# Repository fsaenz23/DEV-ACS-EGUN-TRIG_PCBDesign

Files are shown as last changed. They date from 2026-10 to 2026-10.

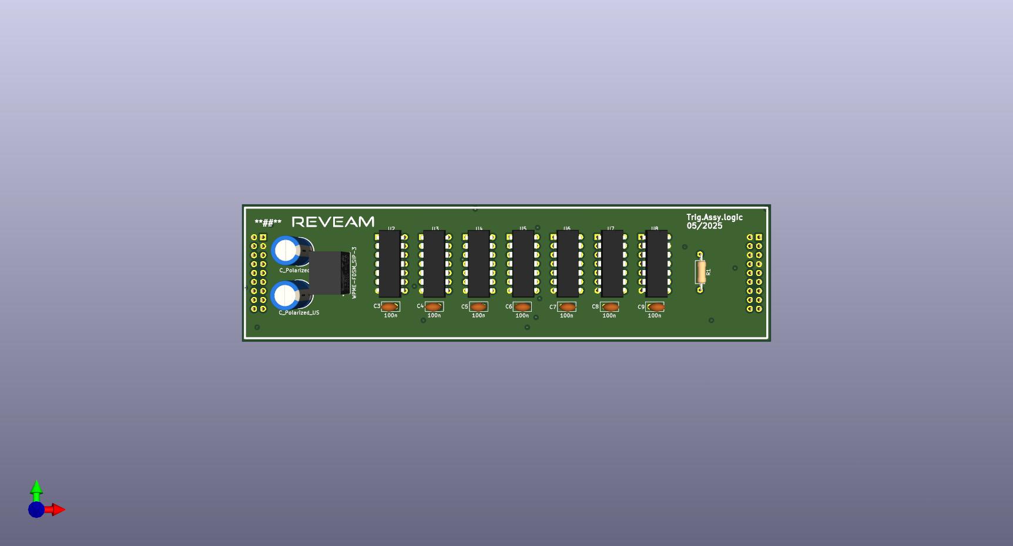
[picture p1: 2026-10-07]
Definition/Drawings/exports/Logic_Board/logicboard.jpg

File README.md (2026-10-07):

# DEV-ACS-EGUN-TRIG_PCBDesign

> The human/operator **front door** (fw-T4.C1.S1.SS4): it orients + routes, and links to deeper resources
> rather than restating them. Agents start at [`AGENTS.md`](AGENTS.md).

## What this is

This repository holds the **printed-circuit-board design of the Trigger Board Assembly** in the Reveam
Accelerator Control System (ACS): a 6-layer Base board and a 4-layer Logic board that plug together and
gate and drive a trigger pulse with isolated status feedback. It is for the engineers who maintain,
review, reorder, or later redesign the boards. It carries the KiCad sources, released Gerbers and reorder
kit, bills of materials, and system documentation, identified independently of any facility the assembly
is later instanced into.

Structural role: `asset-bearing Project`; `project_type`: `product`. asset_id / project_id:
`DEV-ACS-EGUN-TRIG_PCBDesign` (ACS -> EGUN -> TRIG, project-type token `PCBDesign`; cs-T5.C1.S3 /
cs-T5.C1.S17.SS1).

## Scope (fw-T11.C1.S1.SS1)

- **Subject:** the two-board Trigger Board Assembly PCB design (schematics, layouts, BOM, released
  fabrication outputs, system documentation).
- **Axis:** the asset itself -- the PCB design content.
- **Excludes:** firmware or control code (none exists; discrete logic); facility-side instancing
  (E-coded facility repos via `type_ref`); the governance bylaws (FW + CS, consumed as pinned
  submodules); the vendor fiber evaluation boards plugged into J7/J10; the planned all-SMD redesign
  (future, will branch from this baseline); and sibling ACS boards.

This human-prose Scope MUST agree with the machine-readable `scope:` block in
[`compatibility.yaml`](compatibility.yaml) (fw-T11.C1.S1.SS2).

## Status

- **Status:** Phase-2 bootstrap complete (pre-release, `v0.1.0`); the boards themselves are released and in production.
- **Owner:** Francisco Saenz (party `pty-francisco-saenz`; EntraID `fsaenz`). See [`Workflows/ownership/parties.yaml`](Workflows/ownership/parties.yaml).
- **Version:** see [`VERSION`](VERSION) (this repo's own rev). The full multi-module composition cover is the
  document meta-frontpage's job (fw-T8.C1.S11.SS8); this README states this repo's rev and links onward.

## Where things are (routing map)

- [`AGENTS.md`](AGENTS.md) -- **agents start here** (the operating contract + session-start reading order, fw-T7.C1.S1).
- [`BOOTSTRAP.md`](BOOTSTRAP.md) -- the Phase-2 setup steps this repo was scaffolded with.
- [`Definition/`](Definition/) -- the design content: `Drawings/` (KiCad sources + exports), `Fabrication/` (Gerbers, reorder kit), `Equipment/` (BOMs), `Architecture/`, `Calculations/`, `Narratives/`.
- [`Workflows/`](Workflows/) -- the canonical lifecycle scripts (`validate` / `push` / `pull` / `tag` / `deliver`); how to run them: fw-T3.C1.S3 / fw-T3.C1.S9.
- [`Project/STANDING-STATE.md`](Project/STANDING-STATE.md) -- standing state for resuming work (plus optional `Project/dev-tasks/`, fw-T7.C1.S18 / fw-T4.C1.S17).
- [`change-log.md`](change-log.md) + [`minutes/`](minutes/) -- the history of what shipped and why.
- [`docs/`](docs/) -- human documentation (README / FUNCTIONAL / INTERFACES / CHANGES).
- [`Governance/`](Governance/) -- how this repo is governed (the consumed governance submodules + any local governance).

## How to use it

- **Operators:** run the `Workflows/` scripts in order -- `validate.ps1` -> `push.ps1` -> `tag.ps1` (`pull.ps1` to sync, `deliver.ps1` to cut a delivery baseline). Details: fw-T3.C1.S3.
- **Agents:** read `AGENTS.md` first (it routes you to the bylaws + guides).
- **Reordering boards:** start at [`Definition/Fabrication/README.md`](Definition/Fabrication/README.md).

---

*Map, not manual (fw-T4.C1.S1.SS4): this README points to `AGENTS.md`, the bylaws, and the scripts -- it does not restate them (single-source, fw-T11.C1.S2). Keep it current at release (status + version); the routing map is mostly static. `README.md` (humans) and `AGENTS.md` (agents) are the two parallel front doors.*

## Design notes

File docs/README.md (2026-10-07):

# DEV-ACS-EGUN-TRIG_PCBDesign

## Overview

This module is the printed-circuit-board design of the **Trigger Board Assembly** in the Reveam
Accelerator Control System (ACS): two stacked 1.6 mm boards, a 6-layer Base board and a 4-layer
Logic board, that accept a trigger, gate it with inhibit and mode logic, and drive the output
pulse while reporting isolated status. It holds the KiCad schematic and layout sources, the
released fabrication outputs, the bill of materials, and the system documentation. It is a design
artifact (`project_type: product`), identified independently of any facility it is later instanced
into. The released boards are in production; this repo records them as the baseline.

## Owner

Accountable owner: **Francisco Saenz** (party `pty-francisco-saenz`; EntraID `fsaenz`; see
[`Workflows/ownership/parties.yaml`](../Workflows/ownership/parties.yaml) and the per-system
record in [`Workflows/ownership/stakeholders.yaml`](../Workflows/ownership/stakeholders.yaml)).
This project runs `workflow_mode: direct` (single-committer; commits land on the main branch).

## Scope

Scope is declared machine-readably in [`compatibility.yaml`](../compatibility.yaml) per
fw-T11.C1.S1.SS2 and in human prose in the repo-root [`README.md`](../README.md) per
fw-T11.C1.S1.SS1. In short: this repo governs the two-board trigger assembly design content only.
It excludes firmware or control code, facility-side instancing, the consumed governance bylaws,
the vendor fiber evaluation boards, the future all-SMD redesign, and sibling ACS boards.

## How to use

Operators run the `Workflows/*.ps1` lifecycle scripts (`validate` -> `push` -> `tag`; `pull` to
sync, `deliver` to cut a delivery baseline) rather than raw git (fw-T3.C1.S3). Design content
lives under `Definition/`: `Drawings/` (KiCad sources, `exports/` for PDFs and renders),
`Fabrication/` (Gerbers and the JLCPCB reorder kit), `Equipment/` (BOMs), `Architecture/` (block
diagram), `Calculations/` (Falstad simulation) and `Narratives/` (system documentation and design
notes). To reorder bare boards start at `Definition/Fabrication/README.md`. Agents read
[`AGENTS.md`](../AGENTS.md) first.

## Where to look next

See [`FUNCTIONAL.md`](FUNCTIONAL.md) for what the assembly does, [`INTERFACES.md`](INTERFACES.md)
for its provided / required interfaces (narrating [`interfaces.yaml`](../interfaces.yaml)), and
[`CHANGES.md`](CHANGES.md) for how the design has evolved. The append-only ledger is
[`change-log.md`](../change-log.md); resumable state is
[`Project/STANDING-STATE.md`](../Project/STANDING-STATE.md). The full pin-by-pin reference is
`Definition/Narratives/trigger-board-system-documentation.pdf`.

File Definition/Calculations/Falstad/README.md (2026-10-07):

# Falstad simulation
- Final_Circuit.txt: Falstad circuit export (File > Import From Text in Falstad's circuit simulator to open it). Whole-system simulation of the trigger board assembly, made by Alex; one file for the assembly, not one per board.

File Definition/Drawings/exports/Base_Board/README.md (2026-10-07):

Add 3D renders here (KiCad: View > 3D Viewer > File > Export Current View as PNG). Top, bottom and an angled view per board.

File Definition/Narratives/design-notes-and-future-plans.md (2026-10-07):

# Design notes and future plans

This released version is the baseline. The all-SMD version will branch from it.

Recorded 2026-10-07 from the designer (Francisco). The released boards are in production and stay as they are.

## As-built decisions
- The fiber link uses modified fiber evaluation boards, not on-board optics. They plug into the base board headers J7 (output) and J10 (input). They were chosen because they were what Mouser/DigiKey had in stock.
- The evaluation board is AFBR-0548Z (Mouser 630-AFBR-0548Z), one board listed for J7 and J10 in Final_Trigger_Board_BOM.xlsx. Modification: the bent (right-angle) interface pins were removed and replaced with straight pins pointing vertically down, with the longer part of each pin on the side opposite the fiber ports, so the board plugs into the base board headers J7 and J10. The replacement pins are generic 3-position, 2.54 mm pitch header (no part number), cut from a longer strip on hand.
- C12 (100 uF 25 V) is a regular electrolytic capacitor from an Amazon capacitor kit (no part number; D 5.18 mm, H 11.37 mm, lead pitch 1.77 mm as bent), with its leads bent so the top PCB does not hit it. The original Final BOM MPN did not match and was replaced with "kit part".
- Logic R1 (10 k, 1%) is a resistor from a resistor kit (bands brown-black-black-red-brown), no part number. The original Final BOM MPN did not match and was replaced with "kit part".
- Final testing (Final Testing sheet of the BOM): two assemblies passed all 22 tests, including BNC and fiber input/output.
- Surface finish was ordered differently per board (base: ENIG with resin-plugged vias; logic: leaded HASL with oil-plugged vias). Keep as ordered for now. This likely explains why the two boards look different (gold vs silver pads), but that has not been confirmed with the fab.
- Orders: base 9354260A_Y6, logic 9354260A_Y8 (JLCPCB). Ordered files match the files in Base_Board/Gerbers and Logic_Board/Gerbers.

## Future plans (not started)
1. Redesign with all-SMD parts so the boards can be assembled with parts placed by the fab (SMT assembly), replacing the through-hole ICs, networks and connectors where possible.
2. Remove the fiber evaluation boards and put the fiber transmitter/receiver on the board itself. The supporting passives for those parts are only needed at that point.
3. With SMD parts, consider merging the base and logic boards into one board sized to fit the Phoenix enclosure used for this assembly.

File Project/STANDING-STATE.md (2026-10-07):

---
current_version: dev-acs-egun-trig-pcbdesign-v0.1.0
---

# Standing State

> Per fw-T7.C1.S18.SS1 -- the MANDATORY agent-resume record (Session Continuity & Roadmap Maintenance).
> A new or replacement agent reads this FIRST to resume (SS1), and keeps it current as work proceeds and
> before handing off (SS2). Pairs with the OPTIONAL dev-tracking surface (Project/dev-tasks/, fw-T4.C1.S17,
> if enabled) and the latest change-log / minutes.

## Operator-engagement block (FW-canonical default; re-surfaced per fw-T7.C1.S18.SS3)

Per fw-T7.C1.S18.SS3, paste this block verbatim at the top of every resume / handoff / continuation
prompt so a fresh agent is reminded how the operator wants to be engaged. The block CONTENT is
single-sourced from FW's pinned operator-engagement-block.md (fw-T11.C1.S2) and inlined below at
scaffold time; this project MAY override or extend its own copy, but the re-surfacing obligation
itself is not overridable.

> FALLBACK POINTER (pinned FW operator-engagement-block.md absent at emit time -- NOT the canonical text).
> Read the canonical block from the pinned submodule at
> Governance/_GOV-DesignFramework/Definition/References/templates/operator-engagement-block.md and paste
> it here verbatim. Per fw-T7.C1.S18.SS3 this block is re-surfaced at every resume / handoff; per
> fw-T11.C1.S2 its content is single-sourced from the FW artifact, never hardcoded in a consumer.

## Current standing state
- Phase: Phase 2 content populated 2026-10-07 (uncommitted); name gate CANONICAL, validate.ps1 PASS
- Classification: DEV-ACS-EGUN-TRIG_PCBDesign (ACS -> EGUN -> TRIG; function TimingSignal; type-class PCB; discipline D040)
- Owner: pty-francisco-saenz (EntraID fsaenz)
- Layout: flat (no eigen-module; no composition.yaml); two boards under Definition/Drawings/{Base_Board,Logic_Board}
- Design content: released Base ("pin version") + Logic (rev 0.2) boards; source package C:\Repos\Trigger_Board_Package left untouched
- Pins: see compatibility.yaml (governance_pins)
- Last shipped: none yet

## Next steps
- [x] Name gate: CANONICAL (advisory only: PCBDesign not in catalogued project-type set).
- [x] Workflows/validate.ps1: PASS, 0 errors.
- [ ] Commit + push via Workflows/push.ps1 (choose remote); tag via Workflows/tag.ps1.

## Open decisions / parked
- Two ORDER_SPEC.md files fail Definition/Fabrication/CHECKSUMS.sha256 (edited after checksums); regenerate if wanted.
- Functional descriptions in the system documentation (section 1) still to be confirmed against design intent.
- Optional full Gerber check (silkscreen, paste, pad shapes) not done.

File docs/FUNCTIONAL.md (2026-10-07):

# DEV-ACS-EGUN-TRIG_PCBDesign -- Functional Description

## Purpose

The assembly receives an external trigger, decides whether it may pass, and drives the resulting
output pulse, while reporting its state through isolated status outputs. It supports normal
(continuous) and one-shot operation, local and remote mode selection, and three independent
external inhibit inputs. Functional behavior below is derived from the schematic netlist and
should be read against design intent (see the system documentation, section 1).

## Inputs

The assembly consumes a trigger on BNC J6 or fiber header J10 (selected by JP2, with an optional
50 ohm termination on JP3), 24 V DC power on terminal block J1, a separate external 24 V for the
isolated I/O, three opto-isolated inhibit inputs, external one-shot select and arm inputs, and
local operator controls (mode switches SW2/SW3 and the one-shot push button SW1). These
correspond to the `required` interfaces in [`interfaces.yaml`](../interfaces.yaml).

## Outputs

The assembly produces the gated trigger pulse, driven by IC1 (IXDN614PI) onto BNC J5 or fiber
header J7 (selected by JP1, with an optional 50 ohm load on JP4), and opto-isolated status
feedback on terminal block J3 (remote, local, armed, one-shot, normal, power, trigger and
inhibit-summary states). These correspond to the `provided` interfaces in
[`interfaces.yaml`](../interfaces.yaml).

## Operating modes

Local and remote selection (SW2) and normal versus one-shot operation (SW3, with the SW1 push
button or the external arm / one-shot inputs) set the mode; the Logic board state logic produces
the armed, one-shot, normal and local / remote status. In any mode, an asserted inhibit (inputs
1 to 3, summed in the Base board logic) stops output pulses. Timing is set by monostables U4
(74LS221) and U9 (74AHCT123) with the component values listed in the system documentation.
Final testing recorded 22 tests passed on two assemblies, covering BNC and fiber input and
output, inhibits 1 to 3, the one-shot button, mode switches and the termination jumpers.

## Dependencies

The assembly depends on a 24 V supply for the Base board (the Logic board is fed through board
connector J2) and on an external 24 V for the isolated status and input side. The fiber paths
depend on modified AFBR-0548Z evaluation boards plugged into J7 and J10, which are sourced
separately. Upstream and downstream consumers of the trigger, inhibit and status signals are
facility-side and are bound at instancing. It consumes the pinned FW + CS governance submodules
for structure and lifecycle tooling; it authors none of that governance itself.

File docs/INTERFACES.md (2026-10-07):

# DEV-ACS-EGUN-TRIG_PCBDesign -- Interfaces

This narrates [`interfaces.yaml`](../interfaces.yaml) (fw-T9.C1.S5) for human readers. Each
subsection is keyed by the interface `id`. All interfaces are `lifecycle: active`: the boards are
released and in production. The board-to-board connectors (Base J8 to Logic J1, Base J2 to Logic
J2) are internal to the assembly and are documented in the system documentation, section 2.

## Provided interfaces

- **`trigger-output-bnc`** (`electrical`) -- the gated trigger pulse on BNC J5, driven by IC1
  (IXDN614PI), with an optional 50 ohm load (JP4). Selected with JP1. Change-sensitive on the
  connector, drive level and pulse width.
- **`trigger-output-fiber`** (`optical`) -- the same pulse on 3-pin header J7 (signal, GND, 5 V),
  feeding a fiber transmitter evaluation board. Selected with JP1.
- **`status-outputs`** (`electrical`) -- opto-isolated feedback on terminal block J3: remote,
  local, armed, one-shot, normal, power, trigger and inhibit-summary states plus per-inhibit
  status, powered from the external 24 V.

## Required interfaces

- **`trigger-input-bnc`** (`electrical`) -- external trigger on BNC J6, with optional 50 ohm
  termination (JP3). Selected with JP2.
- **`trigger-input-fiber`** (`optical`) -- external trigger from a fiber receiver evaluation board
  on 3-pin header J10 (signal, GND, 5 V). Selected with JP2.
- **`dc-power-in`** (`electrical`) -- 24 V and ground on J1 pins 1-2; each board's WPME-FDSM
  converter derives 5 V.
- **`isolated-24v-in`** (`electrical`) -- separate external 24 V and return (EXT_24V / EXT_GND) on
  J1 for the isolated I/O side.
- **`inhibit-inputs`** (`electrical`) -- three opto-isolated inhibit inputs on J1; any asserted
  inhibit stops output pulses.
- **`remote-control-inputs`** (`electrical`) -- external one-shot select and arm inputs on J1.

## Bidirectional interfaces

- (none) -- the assembly has no peer-bidirectional interfaces.

## Change-sensitive surfaces

The union of change-sensitive fields: `connector_type`, `logic_level`, `termination`
(trigger-input-bnc); `header_pinout`, `fiber_receiver_module` (trigger-input-fiber);
`connector_type`, `drive_level`, `pulse_width` (trigger-output-bnc); `header_pinout`,
`fiber_transmitter_module` (trigger-output-fiber); `rail_voltage`, `current_budget`,
`terminal_pinout` (dc-power-in); `rail_voltage`, `terminal_pinout` (isolated-24v-in);
`input_polarity`, `isolation`, `terminal_pinout` (inhibit-inputs, remote-control-inputs);
`signal_set`, `isolation`, `terminal_pinout` (status-outputs). A change to any of these alters
what connected equipment must expect -- notify the owners of the connected trigger source,
interlock and monitoring equipment before revising them, and co-change this narrative in the same
commit (fw-T9.C1.S5.SS8).

## Superseded interfaces

- (none)

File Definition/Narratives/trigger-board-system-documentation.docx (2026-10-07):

# Trigger Board Assembly

System documentation: pin-by-pin reference, block diagram, board interconnect and bill of materials

Prepared 2026-10-06 from the released KiCad projects (Base_Board rev "pin version", Logic_Board rev 0.2). No design changes are implied by this document.

# 1. System overview

The Trigger Board Assembly is two stacked 1.6 mm boards: the Base board has 6 copper layers (F.Cu, In1-In4, B.Cu) and the Logic board has 4 (F.Cu, In1, In2, B.Cu). The Logic board (150 x 39 mm) plugs onto the Base board through two 2x9 connectors: Base J8 (socket) mates with Logic J1 (pin header), and Base J2 (socket) mates with Logic J2 (pin header). Each board has its own 24 V to 5 V DC-DC converter.

Functional summary, derived from the schematic netlist (verify against design intent):

- Trigger path: an external trigger enters on BNC J6 or fiber header J10 (JP2 selects), optionally terminated in 50 ohm (JP3), and goes to the Logic board as Trig_In on J8 pin 1. The output pulse is driven by IC1 (IXDN614PI) as Trig_Out onto BNC J5 or fiber header J7 (JP1 selects; JP4 adds a 50 ohm load).
- Gating: three opto-isolated external inhibit inputs (J1 pins 7, 9, 11) and the Logic board decision signal In_from_lgboard are ANDed in U6 to form the IC1 input. JP5 and JP6 can force two of the inhibit channels to 5 V.
- Timing: U4 (74LS221) generates Master_TO_Out and Slave_TO_Out. Unit 1 uses C12 100 uF with R14 22 k (about 1.5 s, estimated 0.7 x R x C); unit 2 uses C4 1 nF with R13 1.5 k (about 1 us). U9 (74AHCT123) stretches the output pulse into Trig_Sts using C13 10 uF and R31 100 k (about 0.45 s, estimated 0.45 x R x C).
- Status: Remote, Local, Armed, OneShot, Normal, Power, Trigger and inhibit-summary states are passed through quad optocouplers (U2, U7, U8) to the isolated terminal block J3, powered from the external 24 V (EXT_24V).
- Mode selection: base switches SW2 and SW3 and push button SW1 drive the switch1/switch2 lines, the Arm/one-shot timer input and the Remote status net toward the Logic board.
- Logic board: NAND/AND/OR logic (U2-U5 SN74ACT00, U6 74AHCT04, U7 74LS08, U8 4075) forms the armed / one-shot / normal / remote-local state logic and returns In_from_lgboard and OR_Out.

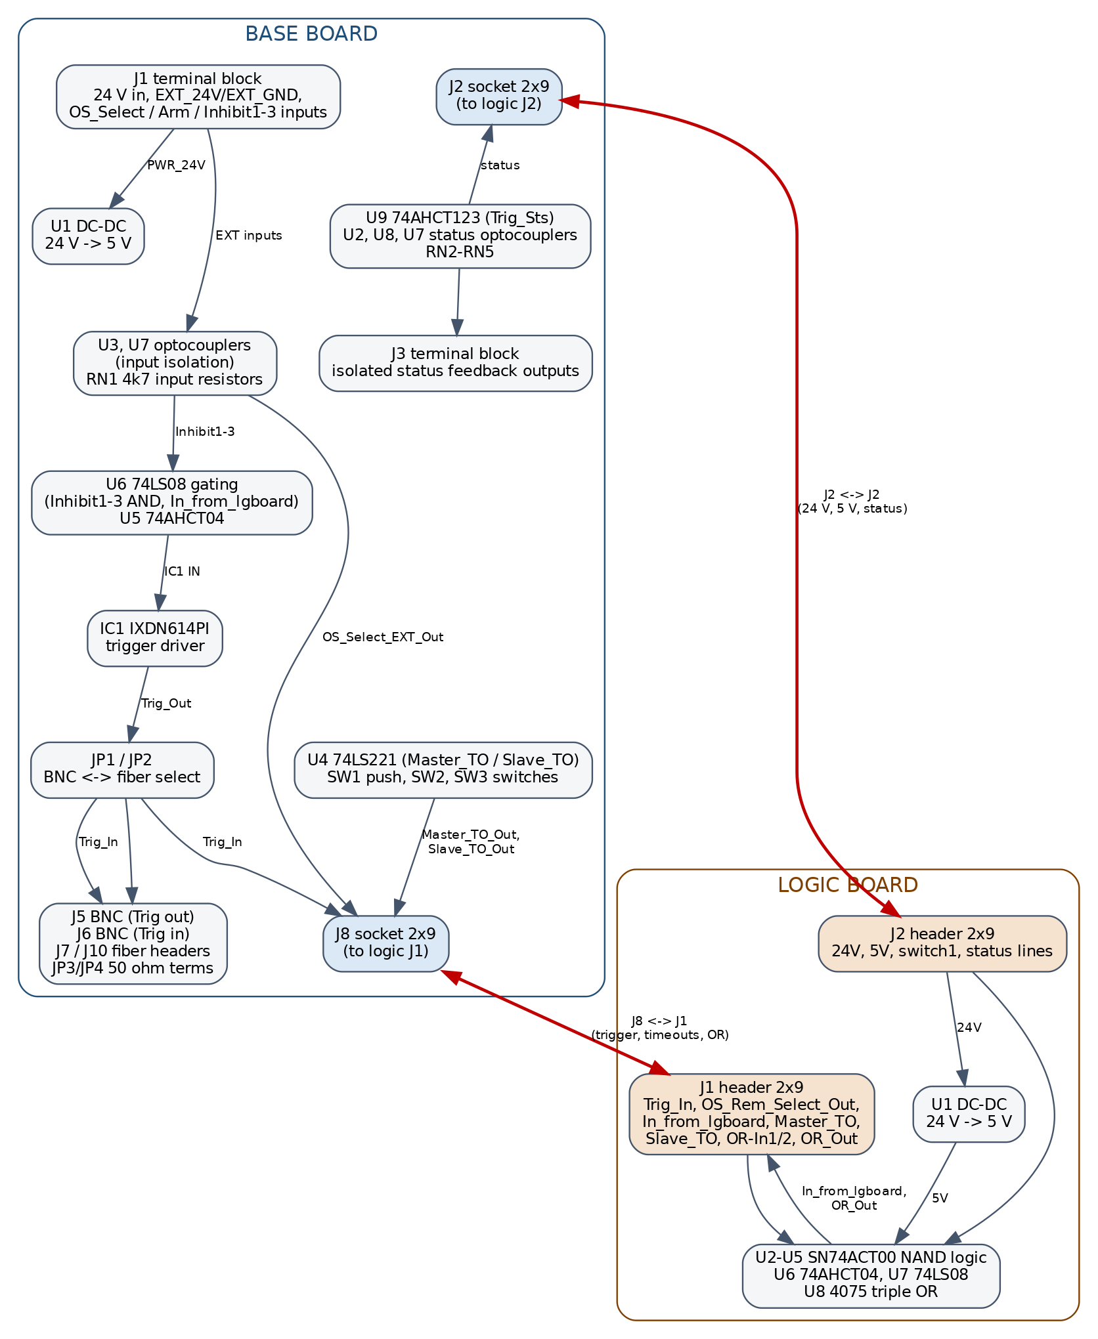
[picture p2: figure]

Figure 1. System block diagram (base + logic). Source: block_diagram.png in this folder.

# 2. Board-to-board interconnect

Base J8 plugs into Logic J1 and Base J2 plugs into Logic J2 (confirmed by the designer). Pins mate n to n; net names match on every populated pin of J8/J1, which supports this.

## 2.1 Base J8 to Logic J1

Pin | Base J8 net | Logic J1 net | Note
1 | Trig_In | Trig_In
2 | GND | GND
3 | OS_Select_EXT_Out | OS_Rem_Select_Out | name differs
4 | In_from_lgboard | In_from_lgboard
5 | Master_TO_Out | Master_TO
6 | GND | GND
7 | GND | GND
8 | Slave_TO_Out | Slave_TO
9 | NC | NC | spare
10 | NC | NC | spare
11 | NC | NC | spare
12 | NC | NC | spare
13 | NC | NC | spare
14 | NC | NC | spare
15 | NC | NC | spare
16 | OR-In1 | OR-In1
17 | OR-In2 | OR-In2
18 | OR_Out | OR_Out

## 2.2 Base J2 to Logic J2

Pin | Base J2 net | Logic J2 net | Note
1 | PWR_24V | 24V
2 | GND | GND
3 | GND | GND
4 | NC | NC | spare
5 | lg_5V_sts | 5V | name differs
6 | switch2pin | Remote Sts | name differs
7 | switch1pin | switch1pin
8 | switch1opt | switch1opt
9 | NC | NC | spare
10 | NC | NC | spare
11 | NC | NC | spare
12 | NC | NC | spare
13 | NC | NC | spare
14 | Normal_Sts | Normal_Sts
15 | OneShot_Sts | OneShot_Sts
16 | Armed_Sts | Armed_Sts
17 | Local_Sts | Local_Sts
18 | Remote Sts | Remote Sts

Notes on differing names (J2): pin 1 is the 24 V rail named PWR_24V on the base and 24V on the logic board. Pin 5 is the logic board 5 V rail, read on the base as lg_5V_sts (5 V present sense). Pin 6 is switch2pin on the base (SW2 output) and lands on the Logic Remote Sts net, which is also on pin 18; so SW2 on the base (the remote/local selector) drives the Logic board Remote Sts net, as intended (confirmed by the designer). Naming differences on J8 (Master_TO_Out vs Master_TO, Slave_TO_Out vs Slave_TO, OS_Select_EXT_Out vs OS_Rem_Select_Out, GND vs /GND) are the same signals.

# 3. Base board pinouts

## 3.1 J1: Field terminal block (Phoenix Contact 1700812, 18 positions): 24 V power, external isolated 24 V and inputs

Pin | Function / pad name | Net
1 | 1 | PWR_24V
2 | 2 | GND
3 | 3 | EXT_24V
4 | 4 | EXT_GND
5 | 5 | OS_Select_EXT
6 | 6 | Arm_OS_EXT
7 | 7 | Inhibit1_EXT
8 | 8 | NC
9 | 9 | Inhibit2_EXT
10 | 10 | Inhibit2_EXT_GND
11 | 11 | Inhibit3_EXT
12 | 12 | Inhibit3_EXT_GND
13 | 13 | NC
14 | 14 | NC
15 | 15 | NC
16 | 16 | NC
17 | 17 | NC
18 | 18 | NC

## 3.2 J3: Field terminal block (Phoenix Contact 1700812, 18 positions): isolated status outputs

Pin | Function / pad name | Net
1 | 1 | NC
2 | 2 | NC
3 | 3 | Rmt_Sts_FB
4 | 4 | Local_Sts_FB
5 | 5 | Inhib_Summ_FB
6 | 6 | Armed_Sts_FB
7 | 7 | Normal_Sts_FB
8 | 8 | OneShot_Sts_FB
9 | 9 | NC
10 | 10 | Pwr_Sts_FB
11 | 11 | NC
12 | 12 | Trg_Sts_FB
13 | 13 | NC
14 | 14 | Inhibit1_Sts_FB
15 | 15 | Inhibit2_Sts
16 | 16 | Inhibit2_Sts_FB
17 | 17 | Inhibit3_Sts
18 | 18 | Inhibit3_Sts_FB

## 3.3 J2: 2x9 socket to Logic J2

Pin | Function / pad name | Net
1 | Pin_1 | PWR_24V
2 | Pin_2 | GND
3 | Pin_3 | GND
4 | Pin_4 | NC
5 | Pin_5 | lg_5V_sts
6 | Pin_6 | switch2pin
7 | Pin_7 | switch1pin
8 | Pin_8 | switch1opt
9 | Pin_9 | NC
10 | Pin_10 | NC
11 | Pin_11 | NC
12 | Pin_12 | NC
13 | Pin_13 | NC
14 | Pin_14 | Normal_Sts
15 | Pin_15 | OneShot_Sts
16 | Pin_16 | Armed_Sts
17 | Pin_17 | Local_Sts
18 | Pin_18 | Remote Sts

## 3.4 J8: 2x9 socket to Logic J1

Pin | Function / pad name | Net
1 | Pin_1 | Trig_In
2 | Pin_2 | GND
3 | Pin_3 | OS_Select_EXT_Out
4 | Pin_4 | In_from_lgboard
5 | Pin_5 | Master_TO_Out
6 | Pin_6 | GND
7 | Pin_7 | GND
8 | Pin_8 | Slave_TO_Out
9 | Pin_9 | NC
10 | Pin_10 | NC
11 | Pin_11 | NC
12 | Pin_12 | NC
13 | Pin_13 | NC
14 | Pin_14 | NC
15 | Pin_15 | NC
16 | Pin_16 | OR-In1
17 | Pin_17 | OR-In2
18 | Pin_18 | OR_Out

## 3.5 J5: BNC, trigger output

Pin | Function / pad name | Net
1 | In | (J5-In)
2 | Ext | GND

## 3.6 J6: BNC, trigger input

Pin | Function / pad name | Net
1 | In | (J6-In)
2 | Ext | GND

## 3.7 J7: 3-pin header, fiber transmitter (output side) connection

Pin | Function / pad name | Net
1 | Pin_1 | (J7-Pin_1)
2 | Pin_2 | GND
3 | Pin_3 | 5V

## 3.8 J10: 3-pin header, fiber receiver (input side) connection

Pin | Function / pad name | Net
1 | Pin_1 | (J10-Pin_1)
2 | Pin_2 | GND
3 | Pin_3 | 5V

J7/J10 fiber header assignments are inferred from jumper wiring (JP1 B to J7 pin 1; JP2 B to J10 pin 1): J7 carries the output trigger, J10 the input trigger. Pin 1 = signal, pin 2 = GND, pin 3 = 5 V.

## 3.9 Jumpers and switches

Ref | Pins and nets
JP1 | 1(A)=(J5-In); 2(C)=Trig_Out; 3(B)=(J7-Pin_1)
JP2 | 1(A)=(J6-In); 2(C)=Trig_In; 3(B)=(J10-Pin_1)
JP3 | 1(A)=(J6-In); 2(B)=(JP3-B)
JP4 | 1(A)=(JP4-A); 2(B)=(J5-In)
JP5 | 1(A)=5V; 2(B)=(JP5-B)
JP6 | 1(A)=5V; 2(B)=(JP6-B)
SW1 | 1(1)=(RN5A-R1.1); 2(2)=(U7-CT1)
SW2 | 1(B)=switch2pin; 2(C)=GND; 3(A)=5V
SW3 | 1(B)=switch1pin; 2(C)=GND; 3(A)=switch1opt

# 4. Logic board pinouts

## 4.1 J1: 2x9 pin header to Base J8

Pin | Net
1 | Trig_In
2 | GND
3 | OS_Rem_Select_Out
4 | In_from_lgboard
5 | Master_TO
6 | GND
7 | GND
8 | Slave_TO
9 | NC
10 | NC
11 | NC
12 | NC
13 | NC
14 | NC
15 | NC
16 | OR-In1
17 | OR-In2
18 | OR_Out

## 4.2 J2: 2x9 pin header to Base J2

Pin | Net
1 | 24V
2 | GND
3 | GND
4 | NC
5 | 5V
6 | Remote Sts
7 | switch1pin
8 | switch1opt
9 | NC
10 | NC
11 | NC
12 | NC
13 | NC
14 | Normal_Sts
15 | OneShot_Sts
16 | Armed_Sts
17 | Local_Sts
18 | Remote Sts

# 5. Integrated circuits: pin-by-pin

Net names in parentheses are local nets named after a pin they connect to. NC = no connection.

### Base IC1: IXDN614PI trigger driver (OUT1/OUT2 paralleled)

Pin | Function | Net
1 | VCC_1 | 5V
2 | IN | (IC1-IN)
3 | NC | NC
4 | GND_1 | GND
5 | GND_2 | GND
6 | OUT_1 | Trig_Out
7 | OUT_2 | Trig_Out
8 | VCC_2 | 5V

### Base U1: WPME-FDSM DC-DC, 24 V to 5 V

Pin | Function | Net
1 | 1 | PWR_24V
2 | 2 | GND
3 | 3 | 5V

### Base U2: PS2501L-4 optocoupler: status outputs

Pin | Function | Net
1 | A1 | (RN3D-R4.1)
2 | C1 | GND
3 | A2 | (RN3E-R5.1)
4 | C2 | GND
5 | A3 | (RN4A-R1.1)
6 | C3 | GND
7 | A4 | (RN4B-R2.1)
8 | C4 | GND
9 | ET4 | OneShot_Sts_FB
10 | CT4 | (RN5B-R2.2)
11 | ET3 | Armed_Sts_FB
12 | CT3 | (RN2F-R6.2)
13 | ET2 | Local_Sts_FB
14 | CT2 | (RN2E-R5.2)
15 | ET1 | Rmt_Sts_FB
16 | CT1 | (RN2D-R4.2)

### Base U3: PS2501L-4 optocoupler: external inputs (OS select, inhibits)

Pin | Function | Net
1 | A1 | (RN1A-R1.2)
2 | C1 | EXT_GND
3 | A2 | (RN1B-R2.2)
4 | C2 | EXT_GND
5 | A3 | (RN1C-R3.2)
6 | C3 | Inhibit2_EXT_GND
7 | A4 | (RN1D-R4.2)
8 | C4 | Inhibit3_EXT_GND
9 | ET4 | (JP5-B)
10 | CT4 | 5V
11 | ET3 | (JP6-B)
12 | CT3 | 5V
13 | ET2 | (RN6D-R4.2)
14 | CT2 | 5V
15 | ET1 | GND
16 | CT1 | OS_Select_EXT_Out

### Base U4: 74LS221 dual monostable

Pin | Function | Net
1 | ~{A} | GND
2 | B | (RN5A-R1.1)
3 | ~{CLR} | 5V
4 | ~{Q} | NC
5 | Q | NC
6 | Cext | (U4B-Cext)
7 | RCext | (U4B-RCext)
8 | GND | GND
9 | ~{A} | GND
10 | B | Master_TO_Out
11 | ~{CLR} | 5V
12 | ~{Q} | Slave_TO_Out
13 | Q | Master_TO_Out
14 | Cext | (U4A-Cext)
15 | RCext | (U4A-RCext)
16 | VCC | 5V

### Base U5: 74AHCT04 hex inverter

Pin | Function | Net
1 | | (RN6D-R4.2)
2 | | (RN3A-R1.2)
3 | | (JP6-B)
4 | | (RN3B-R2.2)
5 | | (JP5-B)
6 | | (RN3C-R3.2)
7 | GND | GND
8 | | OR-In2
9 | | lg_5V_sts
10 | | OR-In1
11 | | 5V
12 | | Pwr_Sts
13 | | OR_Out
14 | VCC | 5V

### Base U6: 74LS08 quad AND

Pin | Function | Net
1 | | (RN6D-R4.2)
2 | | (JP6-B)
3 | | (RN8B-R2.2)
4 | | (RN8B-R2.2)
5 | | (JP5-B)
6 | | (RN8C-R3.2)
7 | GND | GND
8 | | Inhib_Sum
9 | | (RN8C-R3.2)
10 | | 5V
11 | | (IC1-IN)
12 | | In_from_lgboard
13 | | (RN8C-R3.2)
14 | VCC | 5V

### Base U7: PS2501L-4 optocoupler: Arm input and inhibit status

Pin | Function | Net
1 | A1 | (RN1E-R5.2)
2 | C1 | EXT_GND
3 | A2 | (RN3A-R1.1)
4 | C2 | GND
5 | A3 | (RN3B-R2.1)
6 | C3 | GND
7 | A4 | (RN3C-R3.1)
8 | C4 | GND
9 | ET4 | Inhibit3_Sts_FB
10 | CT4 | (RN2C-R3.2)
11 | ET3 | Inhibit2_Sts_FB
12 | CT3 | (RN2B-R2.2)
13 | ET2 | Inhibit1_Sts_FB
14 | CT2 | (RN2A-R1.2)
15 | ET1 | (RN5A-R1.1)
16 | CT1 | (U7-CT1)

### Base U8: PS2501L-4 optocoupler: status outputs

Pin | Function | Net
1 | A1 | (RN4C-R3.1)
2 | C1 | GND
3 | A2 | (RN4D-R4.1)
4 | C2 | GND
5 | A3 | (RN4E-R5.1)
6 | C3 | GND
7 | A4 | (RN4F-R6.1)
8 | C4 | GND
9 | ET4 | Inhib_Summ_FB
10 | CT4 | (RN5F-R6.2)
11 | ET3 | Trg_Sts_FB
12 | CT3 | (RN5E-R5.2)
13 | ET2 | Pwr_Sts_FB
14 | CT2 | (RN5D-R4.2)
15 | ET1 | Normal_Sts_FB
16 | CT1 | (RN5C-R3.2)

### Base U9: 74AHCT123 dual monostable

Pin | Function | Net
1 | A | GND
2 | B | Trig_Out
3 | Clr | 5V
4 | ~{Q} | NC
5 | Q | NC
6 | Cext | NC
7 | RCext | NC
8 | GND | GND
9 | A | NC
10 | B | NC
11 | Clr | NC
12 | ~{Q} | NC
13 | Q | Trig_Sts
14 | Cext | GND
15 | RCext | (U9A-RCext)
16 | VCC | 5V

### Logic U1: WPME-FDSM DC-DC, 24 V to 5 V

Pin | Function | Net
1 | 1 | 24V
2 | 2 | GND
3 | 3 | 5V

### Logic U2: SN74ACT00

Pin | Function | Net
1 | | (U2-Pad1)
2 | | Master_TO
3 | | (U2-Pad3)
4 | | (U2-Pad3)
5 | | 5V
6 | | (U2-Pad13)
7 | GND | GND
8 | | (U2-Pad12)
9 | | Slave_TO
10 | | (U2-Pad10)
11 | | (U2-Pad10)
12 | | (U2-Pad12)
13 | | (U2-Pad13)
14 | VCC | 5V

### Logic U3: SN74ACT00

Pin | Function | Net
1 | | (U2-Pad12)
2 | | Trig_In
3 | | (U3-Pad3)
4 | | (U3-Pad4)
5 | | Trig_In
6 | | (U3-Pad12)
7 | GND | GND
8 | | (U3-Pad4)
9 | | (U2-Pad12)
10 | | 5V
11 | | (U3-Pad11)
12 | | (U3-Pad12)
13 | | Master_TO
14 | VCC | 5V

### Logic U4: SN74ACT00

Pin | Function | Net
1 | | (U3-Pad3)
2 | | (U4-Pad2)
3 | | (U4-Pad3)
4 | | (U4-Pad3)
5 | | (U4-Pad5)
6 | | (U4-Pad2)
7 | GND | GND
8 | | (U4-Pad5)
9 | | (U3-Pad11)
10 | | 5V
11 | | (U4-Pad11)
12 | | Trig_In
13 | | 5V
14 | VCC | 5V

### Logic U5: SN74ACT00

Pin | Function | Net
1 | | (U4-Pad3)
2 | | (U4-Pad11)
3 | | (U5-Pad3)
4 | | (U4-Pad2)
5 | | (U4-Pad11)
6 | | (U5-Pad13)
7 | GND | GND
8 | | Armed_Sts
9 | | (U5-Pad3)
10 | | (U2-Pad1)
11 | | (U2-Pad1)
12 | | Armed_Sts
13 | | (U5-Pad13)
14 | VCC | 5V

### Logic U6: 74AHCT04

Pin | Function | Net
1 | | Remote Sts
2 | | Local_Sts
3 | | OneShot_Sts
4 | | Normal_Sts
5 | | OS_Rem_Select_Out
6 | | (U6-Pad6)
7 | GND | GND
8 | | (U6-Pad8)
9 | | switch1pin
10 | | (U6-Pad10)
11 | | Remote Sts
12 | | switch1opt
13 | | Remote Sts
14 | VCC | 5V

### Logic U7: 74LS08

Pin | Function | Net
1 | | Remote Sts
2 | | (U6-Pad6)
3 | | (U7-Pad3)
4 | | (U6-Pad6)
5 | | (U6-Pad8)
6 | | (U7-Pad6)
7 | GND | GND
8 | | (U7-Pad8)
9 | | (U6-Pad8)
10 | | (U6-Pad10)
11 | | In_from_lgboard
12 | | Trig_In
13 | | (U7-Pad13)
14 | VCC | 5V

### Logic U8: 4075 triple OR

Pin | Function | Net
1 | | (U7-Pad3)
2 | | (U7-Pad6)
3 | | switch1pin
4 | | Armed_Sts
5 | | OS_Rem_Select_Out
6 | | (U7-Pad13)
7 | VSS | GND
8 | | (U7-Pad8)
9 | | OneShot_Sts
10 | | OR_Out
11 | | OR-In1
12 | | OR-In2
13 | | GND
14 | VDD | 5V

For 74xx devices, the gate-level pin functions follow the standard pinouts; the table lists the nets as routed.

# 6. Passive networks

Board | Ref | Value | Pin nets
Base | C1 | C_Polarized_US | 1=PWR_24V; 2=GND
Base | C10 | 100n | 1=5V; 2=GND
Base | C11 | 100n | 1=GND; 2=5V
Base | C12 | 100u | 1=(U4A-Cext); 2=(U4A-RCext)
Base | C13 | 10u | 1=(U9A-RCext); 2=GND
Base | C2 | C_Polarized_US | 1=5V; 2=GND
Base | C3 | 100n | 1=GND; 2=5V
Base | C4 | 1n | 1=(U4B-Cext); 2=(U4B-RCext)
Base | C5 | 100n | 1=(RN5A-R1.1); 2=GND
Base | C6 | 100n | 1=GND; 2=5V
Base | C7 | 100n | 1=GND; 2=5V
Base | R13 | 1k5 | 1=(U4B-RCext); 2=5V
Base | R14 | 22k | 1=(U4A-RCext); 2=5V
Base | R16 | 100 | 1=(U7-CT1); 2=5V
Base | R30 | 50_1W | 1=(JP4-A); 2=GND
Base | R31 | 100k | 1=(U9A-RCext); 2=5V
Base | R32 | 50_1W | 1=(JP3-B); 2=GND
Base | RN1 | 4k7 | 1=OS_Select_EXT; 2=(RN1A-R1.2); 3=Inhibit1_EXT; 4=(RN1B-R2.2); 5=Inhibit2_EXT; 6=(RN1C-R3.2); 7=Inhibit3_EXT; 8=(RN1D-R4.2); 9=Arm_OS_EXT; 10=(RN1E-R5.2)
Base | RN2 | 1k | 1=EXT_24V; 2=(RN2A-R1.2); 3=Inhibit2_Sts; 4=(RN2B-R2.2); 5=Inhibit3_Sts; 6=(RN2C-R3.2); 7=EXT_24V; 8=(RN2D-R4.2); 9=EXT_24V; 10=(RN2E-R5.2); 11=EXT_24V; 12=(RN2F-R6.2)
Base | RN3 | 470 | 1=(RN3A-R1.1); 2=(RN3A-R1.2); 3=(RN3B-R2.1); 4=(RN3B-R2.2); 5=(RN3C-R3.1); 6=(RN3C-R3.2); 7=(RN3D-R4.1); 8=Remote Sts; 9=(RN3E-R5.1); 10=Local_Sts
Base | RN4 | 470 | 1=(RN4A-R1.1); 2=Armed_Sts; 3=(RN4B-R2.1); 4=OneShot_Sts; 5=(RN4C-R3.1); 6=Normal_Sts; 7=(RN4D-R4.1); 8=Pwr_Sts; 9=(RN4E-R5.1); 10=Trig_Sts; 11=(RN4F-R6.1); 12=Inhib_Sum
Base | RN5 | 1k | 1=(RN5A-R1.1); 2=GND; 3=EXT_24V; 4=(RN5B-R2.2); 5=EXT_24V; 6=(RN5C-R3.2); 7=EXT_24V; 8=(RN5D-R4.2); 9=EXT_24V; 10=(RN5E-R5.2); 11=EXT_24V; 12=(RN5F-R6.2)
Base | RN6 | 10k | 1=GND; 2=NC; 3=OR_Out; 4=(JP6-B); 5=(RN6D-R4.2)
Base | RN7 | 10k | 1=GND; 2=(RN6D-R4.2); 3=(JP6-B); 4=(JP5-B); 5=lg_5V_sts
Base | RN8 | 10k | 1=GND; 2=(JP5-B); 3=(RN8B-R2.2); 4=(RN8C-R3.2); 5=In_from_lgboard
Logic | C1 | C_Polarized_US | 1=5V; 2=GND
Logic | C2 | C_Polarized_US | 1=24V; 2=GND
Logic | C3 | 100n | 1=GND; 2=5V
Logic | C4 | 100n | 1=GND; 2=5V
Logic | C5 | 100n | 1=GND; 2=5V
Logic | C6 | 100n | 1=GND; 2=5V
Logic | C7 | 100n | 1=GND; 2=5V
Logic | C8 | 100n | 1=GND; 2=5V
Logic | C9 | 100n | 1=GND; 2=5V
Logic | R1 | 10k | 1=Remote Sts; 2=OS_Rem_Select_Out

# 7. Bill of materials

Full BOM, with base and logic breakouts, is in Trigger_Board_System_BOM.xlsx. System totals below (R: ref prefix B = Base, L = Logic).

Qty | Ref(s) | Schematic value | Description | MFR part # | Mouser #
2 | B:C1, B:C2 | C_Polarized_US | 100uF 50V Electrolythic Capacitor | ESL107M050AGMAA | 80-ESL107M050AGMAA
6 | B:C3, B:C5, B:C6, B:C7, B:C10, B:C11 | 100n | 100nF Ceramic disk capacitor | S104Z93Z5VL83L0R | 594-S104Z93Z5VL83L0R
1 | B:C4 | 1n | 1nF Ceramic Disk Capacitor | FA28C0G1H102JNU00 | 810-FA28C0G1H10200
1 | B:C12 | 100u | 100uF 25V Electrolythic Capacitor | Kit part (no part number) | NA
1 | B:C13 | 10u | 10uF Ceramic Disk Capacitor | FG11X7R1H106KRT00 | 810-FG11X7R1H106KRT0
1 | B:IC1 | IXDN614PI | IXYS MOSFET Gate Driver | IXDN614PI | 849-IXDN614PI
1 | B:J1 | J6 | Screw Terminal Blocks | 1725041 | 651-1725041
2 | B:J2, B:J8 | Conn_02x09_Counter_Clockwise | 02x09 Pin Socket | 215307-9 | 571-215307-9
1 | B:J3 | 1700812 | Screw Terminal Blocks | 1725041 | 651-1725041
2 | B:J5, B:J6 | Conn_Coaxial | BNC female PCB mounted Connector | 1-1478204-0 | 571-1-1478204-0
2 | B:J7, B:J10 | Conn_01x03_Pin | Fiber RX/TX Eval boards. | AFBR-0548Z | 630-AFBR-0548Z
2 | B:JP1, B:JP2 | Jumper_3_Open | Jumper Pins (2 pin ones must be modded) - 6 used + 1 spare | 90120-0763 | 538-90120-0763
4 | B:JP3, B:JP4, B:JP5, B:JP6 | Jumper_2_Small_Open | Jumper Pins (2 pin ones must be modded) - 6 used + 1 spare | 90120-0763 | 538-90120-0763
1 | B:R13 | 1k5 | 1K5 ohm 1/4W | MFR-25FBF52-1K5 | 603-MFR-25FBF52-1K5
1 | B:R14 | 22k | 22Kohm 1/4W | MFR-25FTF52-22K | 603-MFR-25FTF52-22K
1 | B:R16 | 100 | 100 ohm 1/4W | MFR-25FBF52-100R | 603-MFR-25FBF52-100R
2 | B:R30, B:R32 | 50_1W | 50-Ohm 1W Resistor | PAC100005009FA1000 | 71-PAC100005009FA100
1 | B:R31 | 100k | 100K ohm 1/4W | MFR-25FTE52-100K | 603-MFR-25FTE52-100K
1 | B:RN1 | 4k7 | Resistor Network Isolated(4k7x05) | 770103472P | 774-770103472P
2 | B:RN2, B:RN5 | 1k | Resistor Network Isolated(1k06) | 4612X-102-102LF | 652-4612X-2LF-1K
1 | B:RN3 | 470 | Resistor Network Isolated (470x05) | 4610X-102-471LF | 652-4610X-2LF-470
1 | B:RN4 | 470 | Resistor Network Isolated (470x06) | 4612X-102-471LF | 652-4612X-2LF-470
3 | B:RN6, B:RN7, B:RN8 | 10k | Resistor Network Bussed(10Kx04) | 4605X-101-103FLF | 652-4605X-101-103FLF
1 | B:SW1 | SW_Push | Tactile switch | TS02-66-60-BK-260-LCR-D | 179-TS026660BK260LCR
2 | B:SW2, B:SW3 | SW_Wuerth_450301014042 | Wuerth Switch | 450301014042 | 710-450301014042
2 | B:U1, L:U1 | WPME-FDSM_SIP-3 | Wuerth Electronik Voltage Regulator | 173010578 | 710-173010578
4 | B:U2, B:U3, B:U7, B:U8 | PS2501L-4-A | 4-Channel OptoCoupler | PS2501-4-A | 551-PS2501-4-A
1 | B:U4 | 74LS221 | Texas Instruments Monostable Multivibrator | SN74LS221NE4 | 595-SN74LS221NE4
2 | B:U5, L:U6 | 74AHCT04 | Texas Instruments Hex Inverter | SN74AHCT04N | 595-SN74AHCT04N
1 | B:U6 | 74LS08 | Texas Instruments 4-Gate AND | SN74LS08N | 595-SN74LS08N
1 | B:U9 | 74AHCT123 | Texas Instruments Monostable Multivibrator | SN74AHCT123AN | 595-SN74AHCT123AN
2 | L:C1, L:C2 | C_Polarized_US | 100uF 50V Electrolythic Capacitor | ESL107M050AGMAA | 80-ESL107M050AGMAA
7 | L:C3, L:C4, L:C5, L:C6, L:C7, L:C8, L:C9 | 100n | 100 nF Ceramic disk capacitor | S104Z93Z5VL83L0R | 594-S104Z93Z5VL83L0R
2 | L:J1, L:J2 | Conn_02x09_Counter_Clockwise | 02x09 Pin Header | 826925-9 | 571-826925-9
1 | L:R1 | 10k | 10K 1% 1/4W Resistor | Kit part (no part number) | NA
4 | L:U2, L:U3, L:U4, L:U5 | SN74ACT00 | Texas Instruments Quad 2-Input NAND | SN74ACT00N | 595-SN74ACT00N
1 | L:U7 | 74LS08 | Texas Instruments 4-Gate AND | SN74LS08N | 595-SN74LS08N
1 | L:U8 | 4075 | Texas Instruments Triple 3-input OR Gate | CD4075BE | 595-CD4075BE

Not on the PCBs (see the Off-Board Items sheet of the BOM spreadsheet): the AFBR-0548Z fiber RX/TX evaluation board (qty 1, plugs into J7 and J10, modified), Phoenix Contact housing parts (2278500, 2278526, 2278542, 2 x 2896238), 6 jumper shunts (JM-2BK-61) and the bare PCBs. The source of part numbers is Final_Trigger_Board_BOM.xlsx.

Total: 72 parts (52 base, 20 logic), excluding bare PCBs, shunts, sockets and hardware.

# 8. BOM reconciliation and open items

Part numbers above come from Final_Trigger_Board_BOM.xlsx matched by reference designator. Every schematic reference appears in that BOM. Differences found:

- C4 and C13: the original Final BOM had the designators swapped. The board is correct (C4 marked 102 = 1 nF, C13 marked 106 = 10 uF, as in the schematic) and Final_Trigger_Board_BOM.xlsx is now corrected.
- C12: the fitted part is a regular 100 uF 25 V electrolytic from a capacitor kit (no part number), measured D 5.18 mm, H 11.37 mm, lead pitch 1.77 mm as bent, with its leads bent so the top PCB does not hit it. This matches the schematic. The original Final BOM MPN reads as 2.2 uF / 100 V and was replaced with kit part.
- Logic R1: the fitted resistor is 10 k, 1% (bands brown-black-black-red-brown), from a resistor kit with no part number. This matches the schematic. The original Final BOM MPN reads as 6.8 k and was replaced with kit part.
- The original Final BOM listed JP7 and JP10. These are the 3-pin 2.54 mm positions where the eval board pins are soldered, i.e. J7 and J10 in the schematic, not extra jumpers; they are not jumpers. There are 6 jumpers (JP1-JP6); the Final BOM quantity of 7 is 6 used plus 1 spare, so item 10 reads JP1-JP6, quantity 7 (6 + 1 spare).
- Logic U1 Mouser number was corrected to 710-173010578 to match base U1, and base U5 to 595-SN74AHCT04N (missing prefix).
- One AFBR-0548Z evaluation board (qty 1) is listed for both J7 and J10. The bent interface pins were removed and replaced with straight pins facing vertically down (longer part of the pins on the side opposite the fiber ports); the replacement pins are generic 3-position, 2.54 mm pitch header (no part number) cut from a longer strip on hand.
- Terminal blocks J1 and J3: the BOM lists 6 blocks of MPN 1725041 for 18 positions each, which resolves the earlier library-text/footprint question if that part is 3-position (not verified).
- Schematic symbol U2/U3/U7/U8 is PS2501L-4-A; the ordered part is PS2501-4-A in a DIP-16 footprint.
- Mating of J8/J1 and J2/J2 is confirmed by the designer (section 2). Functional descriptions in section 1 are derived from the netlist, not from design intent.

# 8.1 Assembly notes

- Fiber evaluation board (AFBR-0548Z): the bent interface pins were removed and replaced with straight pins facing vertically down, the longer part of the pins on the side opposite the fiber ports.
- Logic R1 (10 k, 1%): a resistor from a resistor kit (bands brown-black-black-red-brown), no part number.
- C12 (100 uF, 25 V): a regular electrolytic capacitor from an Amazon capacitor kit (no part number; D 5.18 mm, H 11.37 mm, lead pitch 1.77 mm as bent), with its leads bent so the top (logic) board does not hit it.

# 8.2 Final testing (from the Final Testing sheet)

Two assemblies were tested against 22 items. All items passed on both assemblies, including BNC and fiber input/output, inhibit 1-3, the one-shot button, local/remote and normal/one-shot switches, and the 50-ohm termination jumpers.

Test | Description | Assy 1 | Assy 2
50-ohm termination jumpers | 50 ohms across BNC connectors when jumper present. BNC open if jumper removed. | Pass | Pass
Local-Remote switch | Local and Remote status outputs toggle properly with switch input. | Pass | Pass
Normal-OS switch | Normal and OS feedbacks are triggered appropiately. | Pass | Pass
Power status feedback | HIGH(24V) when PWR and EXT PWR are present | Pass | Pass
Inhibbit Summation Status (inh2 jumper) | Triggered on inh2 jumper | Pass | Pass
Inhibbit Summation Status (inh3 jumper) | Triggered on inh3 jumper | Pass | Pass
Inhibit 1 feedback | triggers HIGH if inhibit 1 input LO and viceversa | Pass | Pass
input selection jumper | Propely labeled and selects the appropiate input | Pass | Pass
output selection jumper | Propely labeled and selects the appropiate output | Pass | Pass
Inhibit 2 jumper | Stops Pulses and relfects properly on INH summation | Pass | Pass
Inhibit 3 jumper | Stops Pulses and relfects properly on INH summation | Pass | Pass
Trigger_sts_fb | tested on BNC triggering | Pass | Pass
OS button | allows one pulse when proper switch setup and button pressede | Pass | Pass
inhibit 2 in/out | inhibit 2 input signal propelry closes the selected voltage on INH2 feedback. | Pass | Pass
inhibit 3 in/out | inhibit 3 input signal propelry closes the selected voltage on INH3 feedback. | Pass | Pass
Remote OS signal input | When swtiches are appropiate, remote OS is selected and Remote OS Signal is received a single pulse is observed at the output | Pass | Pass
BNC input | Input works properly | Pass | Pass
BNC output | Output works properly | Pass | Pass
Fiber input | Input works properly | Pass | Pass
fiber output | Output works properly | Pass | Pass
INH1 stops pulses | When pulsing, INH1 LOW stops the pulses. | Pass | Pass
INH2 stops pulses | When Pulsing INH2 LOW stops the pulses. | Pass | Pass
INH3 stops pulses | When Pulsing INH3 LOW stops the pulses. | Pass | Pass

# 9. Gerber verification (released Gerbers vs KiCad project files)

Checked 2026-10-06 by parsing the released Gerber/drill zips (generated 2025-05-30 by KiCad 8.0.8) and comparing them with Base_Board/KiCad/baseboard.kicad_pcb and Logic_Board/KiCad/logicboard.kicad_pcb. KiCad itself was not available, so the check compares geometry; it is not a byte-for-byte regeneration.

Item | Base board | Logic board
Copper tracks, every layer | all 966 match exactly (position, width) | all 369 match exactly
Zone fills | 22 of 22 identical | 3 of 3 present (count match)
Drill holes (PTH) | 389 of 389 within 1 um; no NPTH holes in either file | 173 of 173 exact
Board outline | 148 lines + 48 arcs, count match | 4 lines, count match
Solder-mask openings | 352 flashes, all at pad positions | 157 flashes, all at pad positions
Not verified | silkscreen, paste, pad/aperture sizes and shapes | same

Result: copper, drills, outline and mask openings in the released Gerbers match the current project files. The base PCB file was last saved 2025-06-17, after the 2025-05-30 Gerbers, but no geometry difference was found, so those later saves did not change the checked items.

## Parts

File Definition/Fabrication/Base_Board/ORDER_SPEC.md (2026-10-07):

# Base board - fabrication order specification

Reorder with: Gerbers_Baseboard-PinVersion.zip (this folder). Same files as Base_Board/Gerbers in the package.

| Item | Value |
| --- | --- |
| Board | Base board, "pin version" (KiCad project: Base_Board/KiCad/baseboard.kicad_pcb) |
| Last order | JLCPCB, order 9354260A_Y6, accounted 2025-05-30 (package: JLCPCB_Order_9354260A_Y6.zip) |
| Layers | 6 (F.Cu, In1-In4, B.Cu) |
| Size | 157.7 x 86.4 mm (from Edge_Cuts; matches the fab job file) |
| Thickness | 1.6 mm, FR-4 |
| Copper | 1 oz outer, 0.5 oz inner |
| Solder mask | Green |
| Silkscreen | White |
| Surface finish | ENIG (immersion gold) |
| Vias | Plugged with resin |
| Min drill | 0.30 mm (37 vias); through-hole sizes 0.6 to 1.524 mm |
| Narrowest track | 0.45 mm |
| Design software | KiCad 8.0.8 |
| Gerber set | 17 files: 6 copper, mask/paste/silk top and bottom, edge cuts, PTH and NPTH drill + drill maps |

Notes: finish differs from the logic board (see its spec); this is intentional: keep ENIG on the base board and reorder with the same finish. The board carries two fiber headers (J7, J10) for modified fiber evaluation boards that are NOT part of this order.
Source: fab job file 4te.json inside the JLCPCB package (Chinese-encoded; translated here).

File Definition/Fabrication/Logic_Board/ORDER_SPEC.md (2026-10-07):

# Logic board - fabrication order specification

Reorder with: Gerbers_Logicboard.zip (this folder). Same files as Logic_Board/Gerbers in the package.

| Item | Value |
| --- | --- |
| Board | Logic board rev 0.2 (KiCad project: Logic_Board/KiCad/logicboard.kicad_pcb) |
| Last order | JLCPCB, order 9354260A_Y8, accounted 2025-06-05. A replacement-file order for an earlier order (Y7) that was missing the drill layer. Package: JLCPCB_Order_9354260A_Y8.zip |
| Layers | 4 (F.Cu, In1, In2, B.Cu) |
| Size | 150.0 x 39.0 mm (from Edge_Cuts; matches the fab job file) |
| Thickness | 1.6 mm, FR-4 |
| Copper | 1 oz outer, 0.5 oz inner |
| Solder mask | Green |
| Silkscreen | White |
| Surface finish | HASL with lead (leaded) |
| Vias | Plugged with soldermask ("oil") |
| Min drill | 0.30 mm (16 vias); other holes 0.8 and 1.0 mm |
| Narrowest track | 0.50 mm |
| Design software | KiCad 8.0.8 |
| Gerber set | 15 files: 4 copper, mask/paste/silk top and bottom, edge cuts, PTH and NPTH drill + drill maps. Must include the drill files. |

Notes: the first Gerber zip without drill files (Archive/Superseded_Fabrication) must NOT be used for ordering. Finish differs from the base board; this is intentional: keep leaded HASL on the logic board and reorder with the same finish.
Source: fab job file 4te.json inside the JLCPCB package (Chinese-encoded; translated here).

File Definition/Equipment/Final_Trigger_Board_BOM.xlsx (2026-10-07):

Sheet: FINAL TESTING
Tested IO or Device | Test Description | Assembly 1 | Assembly 2
50-ohm termination jumpers | 50 ohms across BNC connectors when jumper present. BNC open if jumper removed. | Pass | Pass
Local-Remote switch | Local and Remote status outputs toggle properly with switch input. | Pass | Pass
Normal-OS switch | Normal and OS feedbacks are triggered appropiately. | Pass | Pass
Power status feedback | HIGH(24V) when PWR and EXT PWR are present | Pass | Pass
Inhibbit Summation Status (inh2 jumper) | Triggered on inh2 jumper | Pass | Pass
Inhibbit Summation Status (inh3 jumper) | Triggered on inh3 jumper | Pass | Pass
Inhibit 1 feedback | triggers HIGH if inhibit 1 input LO and viceversa | Pass | Pass
input selection jumper | Propely labeled and selects the appropiate input | Pass | Pass
output selection jumper | Propely labeled and selects the appropiate output | Pass | Pass
Inhibit 2 jumper | Stops Pulses and relfects properly on INH summation | Pass | Pass
Inhibit 3 jumper | Stops Pulses and relfects properly on INH summation | Pass | Pass
Trigger_sts_fb | tested on BNC triggering | Pass | Pass
OS button | allows one pulse when proper switch setup and button pressede | Pass | Pass
inhibit 2 in/out | inhibit 2 input signal propelry closes the selected voltage on INH2 feedback. | Pass | Pass
inhibit 3 in/out | inhibit 3 input signal propelry closes the selected voltage on INH3 feedback. | Pass | Pass
Remote OS signal input | When swtiches are appropiate, remote OS is selected and Remote OS Signal is received a single pulse is observed at the output | Pass | Pass
BNC input | Input works properly | Pass | Pass
BNC output | Output works properly | Pass | Pass
Fiber input | Input works properly | Pass | Pass
fiber output | Output works properly | Pass | Pass
INH1 stops pulses | When pulsing, INH1 LOW stops the pulses. | Pass | Pass
INH2 stops pulses | When Pulsing INH2 LOW stops the pulses. | Pass | Pass
INH3 stops pulses | When Pulsing INH3 LOW stops the pulses. | Pass | Pass

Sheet: FINAL BOM
Item# | Description | Location | Type | PCB ID | Quantity | MFR Part# | Mouser Part #
1 | Tactile switch | Base Board | Button | SW1 | 1 | TS02-66-60-BK-260-LCR-D | 179-TS026660BK260LCR
2 | 100nF Ceramic disk capacitor | Base Board | Capacitor | C3 C5-C7 C10 C11 | 6 | S104Z93Z5VL83L0R | 594-S104Z93Z5VL83L0R
3 | 100uF 50V Electrolythic Capacitor | Base Board | Capacitor | C1 C2 | 2 | ESL107M050AGMAA | 80-ESL107M050AGMAA
4 | 1nF Ceramic Disk Capacitor | Base Board | Capacitor | C4 | 1 | FA28C0G1H102JNU00 | 810-FA28C0G1H10200
5 | 10uF Ceramic Disk Capacitor | Base Board | Capacitor | C13 | 1 | FG11X7R1H106KRT00 | 810-FG11X7R1H106KRT0
6 | 100uF 25V Electrolythic Capacitor | Base Board | Capacitor | C12 | 1 | Kit part (no part number) | NA
7 | BNC female PCB mounted Connector | Base Board | Connector | J5 J6 | 2 | 1-1478204-0 | 571-1-1478204-0
8 | 02x09 Pin Socket | Base Board | Connector | J2 J8 | 2 | 215307-9 | 571-215307-9
9 | Screw Terminal Blocks | Base Board | Connector | J1 J3 | 6 | 1725041 | 651-1725041
10 | Jumper Pins (2 pin ones must be modded) - 6 used + 1 spare | Base Board | Connector | JP1-JP6 | 7 | 90120-0763 | 538-90120-0763
11 | 4-Channel OptoCoupler | Base Board | IC | U2 U3 U7 U8 | 4 | PS2501-4-A | 551-PS2501-4-A
12 | Texas Instruments 4-Gate AND | Base Board | IC | U6 | 1 | SN74LS08N | 595-SN74LS08N
13 | Texas Instruments Monostable Multivibrator | Base Board | IC | U4 | 1 | SN74LS221NE4 | 595-SN74LS221NE4
14 | Wuerth Electronik Voltage Regulator | Base Board | IC | U1 | 1 | 173010578 | 710-173010578
15 | IXYS MOSFET Gate Driver | Base Board | IC | IC1 | 1 | IXDN614PI | 849-IXDN614PI
16 | Texas Instruments Hex Inverter | Base Board | IC | U5 | 1 | SN74AHCT04N | 595-SN74AHCT04N
17 | Texas Instruments Monostable Multivibrator | Base Board | IC | U9 | 1 | SN74AHCT123AN | 595-SN74AHCT123AN
18 | Jumpers | Base Board | Jumper | NA | 6 | JM-2BK-61 | 306-JM-2BK-61
19 | 50-Ohm 1W Resistor | Base Board | Resistor | R30 R32 | 2 | PAC100005009FA1000 | 71-PAC100005009FA100
20 | 22Kohm 1/4W | Base Board | Resistor | R14 | 1 | MFR-25FTF52-22K | 603-MFR-25FTF52-22K
21 | 1K5 ohm 1/4W | Base Board | Resistor | R13 | 1 | MFR-25FBF52-1K5 | 603-MFR-25FBF52-1K5
22 | 100 ohm 1/4W | Base Board | Resistor | R16 | 1 | MFR-25FBF52-100R | 603-MFR-25FBF52-100R
23 | 100K ohm 1/4W | Base Board | Resistor | R31 | 1 | MFR-25FTE52-100K | 603-MFR-25FTE52-100K
24 | Resistor Network Isolated (470x05) | Base Board | Resistor Network | RN3 | 1 | 4610X-102-471LF | 652-4610X-2LF-470
25 | Resistor Network Isolated (470x06) | Base Board | Resistor Network | RN4 | 1 | 4612X-102-471LF | 652-4612X-2LF-470
26 | Resistor Network Isolated(4k7x05) | Base Board | Resistor Network | RN1 | 1 | 770103472P | 774-770103472P
27 | Resistor Network Isolated(1k06) | Base Board | Resistor Network | RN2 RN5 | 2 | 4612X-102-102LF | 652-4612X-2LF-1K
28 | Resistor Network Bussed(10Kx04) | Base Board | Resistor Network | RN6 RN7 RN8 | 3 | 4605X-101-103FLF | 652-4605X-101-103FLF
29 | Wuerth Switch | Base Board | Switch | SW2 SW3 | 2 | 450301014042 | 710-450301014042
30 | Fiber RX/TX Eval boards. | Base Board | Connector | J7 J10 | 1 | AFBR-0548Z | 630-AFBR-0548Z
31 | Base Board PCB empty board | Base Board | PCB | PCB | 1 | NA | NA
32 | 100 nF Ceramic disk capacitor | Logic Board | Capacitor | C3-9 | 7 | S104Z93Z5VL83L0R | 594-S104Z93Z5VL83L0R
33 | 100uF 50V Electrolythic Capacitor | Logic Board | Capacitor | C1 C2 | 2 | ESL107M050AGMAA | 80-ESL107M050AGMAA
34 | 02x09 Pin Header | Logic Board | Connector | J1 J2 | 2 | 826925-9 | 571-826925-9
35 | Texas Instruments Triple 3-input OR Gate | Logic Board | IC | U8 | 1 | CD4075BE | 595-CD4075BE
36 | Texas Instruments Quad 2-Input NAND | Logic Board | IC | U2 U3 U4 U5 | 4 | SN74ACT00N | 595-SN74ACT00N
37 | Texas Instruments Hex Inverter | Logic Board | IC | U6 | 1 | SN74AHCT04N | 595-SN74AHCT04N
38 | Texas Instruments 4-Gate AND | Logic Board | IC | U7 | 1 | SN74LS08N | 595-SN74LS08N
39 | Wuerth Electronik Voltage Regulator | Logic Board | IC | U1 | 1 | 173010578 | 710-173010578
40 | 10K 1% 1/4W Resistor | Logic Board | Resistor | R1 | 1 | Kit part (no part number) | NA
41 | Logic Board PCB empty board | Logic Board | PCB | PCB | 1 | NA | NA
42 | Mounting Base Base Housing(Phoenix Contact) | Housing | Housing | NA | 1 | 2278500 | 651-2278500
43 | Upper Housing Part(Phoeix Contact) | Housing | Housing | NA | 1 | 2278526 | 651-2278526
44 | Housing Cover(Phoeix Contact) | Housing | Housing | NA | 1 | 2278542 | 651-2278542
45 | Housing Filler Plug(Phoeix Contact) | Housing | Housing | NA | 2 | 2896238 | 651-2896238

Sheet: INVENTORY
Useful Inventory.
# | Definition | Location | Type | QTY | MFR Part #
1 | Resistor Network Isolated (470x06) | Base Board | Resistor Network | 3 | 4612X-102-471LF
2 | Resistor Network Isolated (470x05) | Base Board | Resistor Network | 3 | 4610X-102-471LF
3 | Resistor Network Isolated(1k06) | Base Board | Resistor Network | 2 | 4612X-102-102LF
4 | Base Board PCB empty board | Base Board | PCB | 4 | NA
5 | Logic Board PCB empty board | Logic Board | PCB | 4 | NA
6 | 02x09 Pin Header | Logic Board | Connector | 5 | 826925-9
7 | Housing Cover(Phoeix Contact) | Housing | Housing | 1 | 2278542
8 | Resistor Network Isolated(4k7x05) | Base Board | Resistor Network | 3 | 770103472P
9 | Housing Filler Plug(Phoeix Contact) | Housing | Housing | 5 | 2896238
10 | Wuerth Switch | Base Board | Switch | 1 | 450301014042
11 | BNC female PCB mounted Connector | Base Board | Connector | 1 | 1-1478204-0
12 | 02x09 Pin Socket | Base Board | Connector | 1 | 215307-9
13 | Screw Terminal Blocks | Base Board | Connector | 3 | 1725041
14 | Tactile switch | Base Board | Button | 3 | TS02-66-60-BK-260-LCR-D
15 | Resistor Network Bussed(10Kx04) | Base Board | Resistor Network | 4 | 4605X-101-103FLF
16 | Fiber RX/TX Eval boards. | Base Board | Connector | 1 | AFBR-0548Z
17 | Texas Instruments Triple 3-input OR Gate | Logic Board | IC | 6 | CD4075BE
18 | Wuerth Electronik Voltage Regulator | Base Board | IC | 5 | 173010578
19 | Texas Instruments Quad 2-Input NAND | Logic Board | IC | 11 | SN74ACT00N
20 | Texas Instruments Hex Inverter | Base Board | IC | 3 | SN74AHCT04N
21 | IXYS MOSFET Gate Driver | Base Board | IC | 8 | IXDN614PI
22 | Texas Instruments Monostable Multivibrator | Base Board | IC | 10 | SN74LS221NE4
23 | Texas Instruments 4-Gate AND | Logic Board | IC | 14 | SN74LS08N
24 | 4-Channel OptoCoupler | Base Board | IC | 9 | PS2501-4-A
25 | Texas Instruments Monostable Multivibrator | Base Board | IC | 4 | SN74AHCT123AN
26 | 100uF 50V Electrolythic Capacitor | Base Board | Capacitor | 23 | NA

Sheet: CORRECTIONS
Item # | Field | Item | Was | Now | Reason
4 | PCB ID | 1nF Ceramic Disk Capacitor | C13 | C4 | Board marking 102 = 1 nF; schematic C4 = 1n. Designators were swapped.
5 | PCB ID | 10uF Ceramic Disk Capacitor | C4 | C13 | Board marking 106 = 10 uF; schematic C13 = 10u. Designators were swapped.
6 | MFR Part# | 100uF 25V Electrolythic Capacitor | ESK225M100AC3FA | Kit part (no part number) | Fitted part is a regular 100uF 25V electrolytic from a capacitor kit. Original MPN ESK225M100AC3FA reads as 2.2uF/100V.
6 | Mouser Part # | 100uF 25V Electrolythic Capacitor | 80-ESK225M100AC3FA | NA | No orderable number for a kit part.
40 | Description | 10K 1% 1/4W Resistor | 10K 1/4W Resistor | 10K 1% 1/4W Resistor | Bands brown-black-black-red-brown = 10k 1%.
40 | MFR Part# | 10K 1% 1/4W Resistor | MF1/4LCT52R682J | Kit part (no part number) | Fitted part is from a resistor kit. Original MPN MF1/4LCT52R682J reads as 6.8k.
40 | Mouser Part # | 10K 1% 1/4W Resistor | 660-MF1/4LCT52R682J | NA | No orderable number for a kit part.
41 | Location | Logic Board PCB empty board | Base Board | Logic Board | Logic board PCB was listed under Base Board.
INVENTORY 5 | Location | Logic Board PCB empty board | Base Board | Logic Board | Logic board PCB was listed under Base Board.
10 | PCB ID | Jumper Pins (2 pin ones must be modded) | JP1-JP7 JP10 | JP1-JP6 J7 J10 | JP7 and JP10 are the 3-pin 2.54 mm positions where the eval board pins are soldered, i.e. J7 and J10 in the schematic, not extra jumpers. Quantity (7) vs positions (8) still to confirm.
NOT CHANGED - still to confirm
Item 10 (jumper pins): quantity is 7 but there are 8 positions (JP1-JP6, J7, J10). Confirm how many headers were used.
Logic U1 (item 39) Mouser # corrected 710-173010579 -> 710-173010578 (same Würth part, MPN 173010578, as base U1; confirmed by user).
Base U5 (item 16) Mouser # lacks the 595- prefix.
Item 30: one AFBR-0548Z eval board (qty 1) for J7 and J10; the bent interface pins were replaced with straight pins facing vertically down.
Base U5 (item 16) Mouser # corrected SN74AHCT04N -> 595-SN74AHCT04N (added missing 595- prefix; same part as logic U6).
Item 10 (jumper headers): PCB ID corrected to JP1-JP6 (JP7/JP10 were the J7/J10 eval-board pin positions); qty 7 = 6 used + 1 spare (confirmed by user).

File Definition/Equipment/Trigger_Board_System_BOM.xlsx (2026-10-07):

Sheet: System BOM
Item | Board | Qty | Reference(s) | Schematic value | Description (from Final BOM) | Footprint | MFR Part # | Mouser Part # | Notes
1 | Base | 2 | B:C1, B:C2 | C_Polarized_US | 100uF 50V Electrolythic Capacitor | CP_Radial_D6.3mm_P2.50mm | ESL107M050AGMAA | 80-ESL107M050AGMAA
2 | Base | 6 | B:C3, B:C5, B:C6, B:C7, B:C10, B:C11 | 100n | 100nF Ceramic disk capacitor | C_Disc_D4.7mm_W2.5mm_P5.00mm | S104Z93Z5VL83L0R | 594-S104Z93Z5VL83L0R
3 | Base | 1 | B:C4 | 1n | 1nF Ceramic Disk Capacitor | C_Disc_D4.7mm_W2.5mm_P5.00mm | FA28C0G1H102JNU00 | 810-FA28C0G1H10200 | Verified on board: marked 102 (1 nF), matches schematic. Designators were swapped in the original Final BOM and are now corrected
4 | Base | 1 | B:C12 | 100u | 100uF 25V Electrolythic Capacitor | CP_Radial_D4.0mm_P1.50mm | Kit part (no part number) | NA | Regular 100uF 25V electrolytic from a capacitor kit (no part number), leads bent so the top PCB does not hit it. The original Final BOM MPN (reads as 2.2uF/100V) did not match and was replaced
5 | Base | 1 | B:C13 | 10u | 10uF Ceramic Disk Capacitor | C_Disc_D4.7mm_W2.5mm_P5.00mm | FG11X7R1H106KRT00 | 810-FG11X7R1H106KRT0 | Verified on board: marked 106 (10 uF), matches schematic. Designators were swapped in the original Final BOM and are now corrected
6 | Base | 1 | B:IC1 | IXDN614PI | IXYS MOSFET Gate Driver | DIP-8_W7.62mm | IXDN614PI | 849-IXDN614PI
7 | Base | 1 | B:J1 | J6 | Screw Terminal Blocks | 1700812 | 1725041 | 651-1725041 | Final BOM lists 6 terminal blocks (1725041) for J1 and J3 combined
8 | Base | 2 | B:J2, B:J8 | Conn_02x09_Counter_Clockwise | 02x09 Pin Socket | PinSocket_2x09_P2.54mm_Vertical | 215307-9 | 571-215307-9
9 | Base | 1 | B:J3 | 1700812 | Screw Terminal Blocks | 1700812 | 1725041 | 651-1725041 | Final BOM lists 6 terminal blocks (1725041) for J1 and J3 combined
10 | Base | 2 | B:J5, B:J6 | Conn_Coaxial | BNC female PCB mounted Connector | BNC_TEConnectivity_1478204_Vertical | 1-1478204-0 | 571-1-1478204-0
11 | Base | 2 | B:J7, B:J10 | Conn_01x03_Pin | Fiber RX/TX Eval boards. | FanPinHeader_1x03_P2.54mm_Vertical | AFBR-0548Z | 630-AFBR-0548Z | Final BOM: one AFBR-0548Z eval board (qty 1) for J7 and J10; modifications to be documented
12 | Base | 2 | B:JP1, B:JP2 | Jumper_3_Open | Jumper Pins (2 pin ones must be modded) - 6 used + 1 spare | PinHeader_1x03_P2.54mm_Vertical | 90120-0763 | 538-90120-0763 | Final BOM item 10 qty 7 = 6 used (JP1-JP6) + 1 spare; 2-pin ones must be modified
13 | Base | 4 | B:JP3, B:JP4, B:JP5, B:JP6 | Jumper_2_Small_Open | Jumper Pins (2 pin ones must be modded) - 6 used + 1 spare | TestPoint_2Pads_Pitch2.54mm_Drill0.8mm | 90120-0763 | 538-90120-0763 | 2-pin headers must be modified (per Final BOM)
14 | Base | 1 | B:R13 | 1k5 | 1K5 ohm 1/4W | R_Axial_DIN0207_L6.3mm_D2.5mm_P10.16mm_Horizontal | MFR-25FBF52-1K5 | 603-MFR-25FBF52-1K5
15 | Base | 1 | B:R14 | 22k | 22Kohm 1/4W | R_Axial_DIN0207_L6.3mm_D2.5mm_P10.16mm_Horizontal | MFR-25FTF52-22K | 603-MFR-25FTF52-22K
16 | Base | 1 | B:R16 | 100 | 100 ohm 1/4W | R_Axial_DIN0207_L6.3mm_D2.5mm_P10.16mm_Horizontal | MFR-25FBF52-100R | 603-MFR-25FBF52-100R
17 | Base | 2 | B:R30, B:R32 | 50_1W | 50-Ohm 1W Resistor | R_Axial_DIN0411_L9.9mm_D3.6mm_P15.24mm_Horizontal | PAC100005009FA1000 | 71-PAC100005009FA100
18 | Base | 1 | B:R31 | 100k | 100K ohm 1/4W | R_Axial_DIN0207_L6.3mm_D2.5mm_P10.16mm_Horizontal | MFR-25FTE52-100K | 603-MFR-25FTE52-100K
19 | Base | 1 | B:RN1 | 4k7 | Resistor Network Isolated(4k7x05) | R_Array_SIP10 | 770103472P | 774-770103472P
20 | Base | 2 | B:RN2, B:RN5 | 1k | Resistor Network Isolated(1k06) | R_Array_SIP12 | 4612X-102-102LF | 652-4612X-2LF-1K
21 | Base | 1 | B:RN3 | 470 | Resistor Network Isolated (470x05) | R_Array_SIP10 | 4610X-102-471LF | 652-4610X-2LF-470
22 | Base | 1 | B:RN4 | 470 | Resistor Network Isolated (470x06) | R_Array_SIP12 | 4612X-102-471LF | 652-4612X-2LF-470
23 | Base | 3 | B:RN6, B:RN7, B:RN8 | 10k | Resistor Network Bussed(10Kx04) | R_Array_SIP5 | 4605X-101-103FLF | 652-4605X-101-103FLF
24 | Base | 1 | B:SW1 | SW_Push | Tactile switch | SW_PUSH_6mm_H5mm | TS02-66-60-BK-260-LCR-D | 179-TS026660BK260LCR
25 | Base | 2 | B:SW2, B:SW3 | SW_Wuerth_450301014042 | Wuerth Switch | SW_Slide-03_Wuerth-WS-SLTV_10x2.5x6.4_P2.54mm | 450301014042 | 710-450301014042
26 | Both | 2 | B:U1, L:U1 | WPME-FDSM_SIP-3 | Wuerth Electronik Voltage Regulator | CONV_173010578 | 173010578 | 710-173010578 | Same Würth DC-DC regulator as logic U1; Same Würth DC-DC regulator as base U1. Mouser # corrected from 710-173010579 to 710-173010578
27 | Base | 4 | B:U2, B:U3, B:U7, B:U8 | PS2501L-4-A | 4-Channel OptoCoupler | DIP-16_W7.62mm | PS2501-4-A | 551-PS2501-4-A | Schematic symbol PS2501L-4-A; ordered PS2501-4-A (DIP-16)
28 | Base | 1 | B:U4 | 74LS221 | Texas Instruments Monostable Multivibrator | DIP-16_W7.62mm | SN74LS221NE4 | 595-SN74LS221NE4
29 | Both | 2 | B:U5, L:U6 | 74AHCT04 | Texas Instruments Hex Inverter | DIP-14_W7.62mm | SN74AHCT04N | 595-SN74AHCT04N | Mouser # corrected to 595-SN74AHCT04N (595- prefix was missing in the original Final BOM)
30 | Base | 1 | B:U6 | 74LS08 | Texas Instruments 4-Gate AND | DIP-14_W7.62mm | SN74LS08N | 595-SN74LS08N
31 | Base | 1 | B:U9 | 74AHCT123 | Texas Instruments Monostable Multivibrator | DIP-16_W7.62mm | SN74AHCT123AN | 595-SN74AHCT123AN
32 | Logic | 2 | L:C1, L:C2 | C_Polarized_US | 100uF 50V Electrolythic Capacitor | CP_Radial_D8.0mm_P3.80mm | ESL107M050AGMAA | 80-ESL107M050AGMAA
33 | Logic | 7 | L:C3, L:C4, L:C5, L:C6, L:C7, L:C8, L:C9 | 100n | 100 nF Ceramic disk capacitor | C_Disc_D5.0mm_W2.5mm_P2.50mm | S104Z93Z5VL83L0R | 594-S104Z93Z5VL83L0R
34 | Logic | 2 | L:J1, L:J2 | Conn_02x09_Counter_Clockwise | 02x09 Pin Header | PinHeader_2x09_P2.54mm_Vertical | 826925-9 | 571-826925-9
35 | Logic | 1 | L:R1 | 10k | 10K 1% 1/4W Resistor | R_Axial_DIN0207_L6.3mm_D2.5mm_P10.16mm_Horizontal | Kit part (no part number) | NA | Verified on board: bands brown-black-black-red-brown = 10k 1%, matches schematic. From a resistor kit (no part number). The original Final BOM MPN (reads as 6.8k) did not match and was replaced
36 | Logic | 4 | L:U2, L:U3, L:U4, L:U5 | SN74ACT00 | Texas Instruments Quad 2-Input NAND | DIP-14_W7.62mm | SN74ACT00N | 595-SN74ACT00N
37 | Logic | 1 | L:U7 | 74LS08 | Texas Instruments 4-Gate AND | DIP-14_W7.62mm | SN74LS08N | 595-SN74LS08N
38 | Logic | 1 | L:U8 | 4075 | Texas Instruments Triple 3-input OR Gate | DIP-14_W7.62mm | CD4075BE | 595-CD4075BE
 |  |  | Total parts (excl. PCBs, shunts, hardware)

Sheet: Base BOM
Item | Board | Qty | Reference(s) | Schematic value | Description (from Final BOM) | Footprint | MFR Part # | Mouser Part # | Notes
1 | Base | 2 | C1, C2 | C_Polarized_US | 100uF 50V Electrolythic Capacitor | CP_Radial_D6.3mm_P2.50mm | ESL107M050AGMAA | 80-ESL107M050AGMAA
2 | Base | 6 | C3, C5, C6, C7, C10, C11 | 100n | 100nF Ceramic disk capacitor | C_Disc_D4.7mm_W2.5mm_P5.00mm | S104Z93Z5VL83L0R | 594-S104Z93Z5VL83L0R
3 | Base | 1 | C4 | 1n | 1nF Ceramic Disk Capacitor | C_Disc_D4.7mm_W2.5mm_P5.00mm | FA28C0G1H102JNU00 | 810-FA28C0G1H10200 | Verified on board: marked 102 (1 nF), matches schematic. Designators were swapped in the original Final BOM and are now corrected
4 | Base | 1 | C12 | 100u | 100uF 25V Electrolythic Capacitor | CP_Radial_D4.0mm_P1.50mm | Kit part (no part number) | NA | Regular 100uF 25V electrolytic from a capacitor kit (no part number), leads bent so the top PCB does not hit it. The original Final BOM MPN (reads as 2.2uF/100V) did not match and was replaced
5 | Base | 1 | C13 | 10u | 10uF Ceramic Disk Capacitor | C_Disc_D4.7mm_W2.5mm_P5.00mm | FG11X7R1H106KRT00 | 810-FG11X7R1H106KRT0 | Verified on board: marked 106 (10 uF), matches schematic. Designators were swapped in the original Final BOM and are now corrected
6 | Base | 1 | IC1 | IXDN614PI | IXYS MOSFET Gate Driver | DIP-8_W7.62mm | IXDN614PI | 849-IXDN614PI
7 | Base | 1 | J1 | J6 | Screw Terminal Blocks | 1700812 | 1725041 | 651-1725041 | Final BOM lists 6 terminal blocks (1725041) for J1 and J3 combined
8 | Base | 2 | J2, J8 | Conn_02x09_Counter_Clockwise | 02x09 Pin Socket | PinSocket_2x09_P2.54mm_Vertical | 215307-9 | 571-215307-9
9 | Base | 1 | J3 | 1700812 | Screw Terminal Blocks | 1700812 | 1725041 | 651-1725041 | Final BOM lists 6 terminal blocks (1725041) for J1 and J3 combined
10 | Base | 2 | J5, J6 | Conn_Coaxial | BNC female PCB mounted Connector | BNC_TEConnectivity_1478204_Vertical | 1-1478204-0 | 571-1-1478204-0
11 | Base | 2 | J7, J10 | Conn_01x03_Pin | Fiber RX/TX Eval boards. | FanPinHeader_1x03_P2.54mm_Vertical | AFBR-0548Z | 630-AFBR-0548Z | Final BOM: one AFBR-0548Z eval board (qty 1) for J7 and J10; modifications to be documented
12 | Base | 2 | JP1, JP2 | Jumper_3_Open | Jumper Pins (2 pin ones must be modded) - 6 used + 1 spare | PinHeader_1x03_P2.54mm_Vertical | 90120-0763 | 538-90120-0763 | Final BOM item 10 qty 7 = 6 used (JP1-JP6) + 1 spare; 2-pin ones must be modified
13 | Base | 4 | JP3, JP4, JP5, JP6 | Jumper_2_Small_Open | Jumper Pins (2 pin ones must be modded) - 6 used + 1 spare | TestPoint_2Pads_Pitch2.54mm_Drill0.8mm | 90120-0763 | 538-90120-0763 | 2-pin headers must be modified (per Final BOM)
14 | Base | 1 | R13 | 1k5 | 1K5 ohm 1/4W | R_Axial_DIN0207_L6.3mm_D2.5mm_P10.16mm_Horizontal | MFR-25FBF52-1K5 | 603-MFR-25FBF52-1K5
15 | Base | 1 | R14 | 22k | 22Kohm 1/4W | R_Axial_DIN0207_L6.3mm_D2.5mm_P10.16mm_Horizontal | MFR-25FTF52-22K | 603-MFR-25FTF52-22K
16 | Base | 1 | R16 | 100 | 100 ohm 1/4W | R_Axial_DIN0207_L6.3mm_D2.5mm_P10.16mm_Horizontal | MFR-25FBF52-100R | 603-MFR-25FBF52-100R
17 | Base | 2 | R30, R32 | 50_1W | 50-Ohm 1W Resistor | R_Axial_DIN0411_L9.9mm_D3.6mm_P15.24mm_Horizontal | PAC100005009FA1000 | 71-PAC100005009FA100
18 | Base | 1 | R31 | 100k | 100K ohm 1/4W | R_Axial_DIN0207_L6.3mm_D2.5mm_P10.16mm_Horizontal | MFR-25FTE52-100K | 603-MFR-25FTE52-100K
19 | Base | 1 | RN1 | 4k7 | Resistor Network Isolated(4k7x05) | R_Array_SIP10 | 770103472P | 774-770103472P
20 | Base | 2 | RN2, RN5 | 1k | Resistor Network Isolated(1k06) | R_Array_SIP12 | 4612X-102-102LF | 652-4612X-2LF-1K
21 | Base | 1 | RN3 | 470 | Resistor Network Isolated (470x05) | R_Array_SIP10 | 4610X-102-471LF | 652-4610X-2LF-470
22 | Base | 1 | RN4 | 470 | Resistor Network Isolated (470x06) | R_Array_SIP12 | 4612X-102-471LF | 652-4612X-2LF-470
23 | Base | 3 | RN6, RN7, RN8 | 10k | Resistor Network Bussed(10Kx04) | R_Array_SIP5 | 4605X-101-103FLF | 652-4605X-101-103FLF
24 | Base | 1 | SW1 | SW_Push | Tactile switch | SW_PUSH_6mm_H5mm | TS02-66-60-BK-260-LCR-D | 179-TS026660BK260LCR
25 | Base | 2 | SW2, SW3 | SW_Wuerth_450301014042 | Wuerth Switch | SW_Slide-03_Wuerth-WS-SLTV_10x2.5x6.4_P2.54mm | 450301014042 | 710-450301014042
26 | Base | 1 | U1 | WPME-FDSM_SIP-3 | Wuerth Electronik Voltage Regulator | CONV_173010578 | 173010578 | 710-173010578 | Same Würth DC-DC regulator as logic U1
27 | Base | 4 | U2, U3, U7, U8 | PS2501L-4-A | 4-Channel OptoCoupler | DIP-16_W7.62mm | PS2501-4-A | 551-PS2501-4-A | Schematic symbol PS2501L-4-A; ordered PS2501-4-A (DIP-16)
28 | Base | 1 | U4 | 74LS221 | Texas Instruments Monostable Multivibrator | DIP-16_W7.62mm | SN74LS221NE4 | 595-SN74LS221NE4
29 | Base | 1 | U5 | 74AHCT04 | Texas Instruments Hex Inverter | DIP-14_W7.62mm | SN74AHCT04N | 595-SN74AHCT04N | Mouser # corrected to 595-SN74AHCT04N (595- prefix was missing in the original Final BOM)
30 | Base | 1 | U6 | 74LS08 | Texas Instruments 4-Gate AND | DIP-14_W7.62mm | SN74LS08N | 595-SN74LS08N
31 | Base | 1 | U9 | 74AHCT123 | Texas Instruments Monostable Multivibrator | DIP-16_W7.62mm | SN74AHCT123AN | 595-SN74AHCT123AN

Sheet: Logic BOM
Item | Board | Qty | Reference(s) | Schematic value | Description (from Final BOM) | Footprint | MFR Part # | Mouser Part # | Notes
1 | Logic | 2 | C1, C2 | C_Polarized_US | 100uF 50V Electrolythic Capacitor | CP_Radial_D8.0mm_P3.80mm | ESL107M050AGMAA | 80-ESL107M050AGMAA
2 | Logic | 7 | C3, C4, C5, C6, C7, C8, C9 | 100n | 100 nF Ceramic disk capacitor | C_Disc_D5.0mm_W2.5mm_P2.50mm | S104Z93Z5VL83L0R | 594-S104Z93Z5VL83L0R
3 | Logic | 2 | J1, J2 | Conn_02x09_Counter_Clockwise | 02x09 Pin Header | PinHeader_2x09_P2.54mm_Vertical | 826925-9 | 571-826925-9
4 | Logic | 1 | R1 | 10k | 10K 1% 1/4W Resistor | R_Axial_DIN0207_L6.3mm_D2.5mm_P10.16mm_Horizontal | Kit part (no part number) | NA | Verified on board: bands brown-black-black-red-brown = 10k 1%, matches schematic. From a resistor kit (no part number). The original Final BOM MPN (reads as 6.8k) did not match and was replaced
5 | Logic | 1 | U1 | WPME-FDSM_SIP-3 | Wuerth Electronik Voltage Regulator | CONV_173010578 | 173010578 | 710-173010578 | Same Würth DC-DC regulator as base U1. Mouser # corrected from 710-173010579 to 710-173010578
6 | Logic | 4 | U2, U3, U4, U5 | SN74ACT00 | Texas Instruments Quad 2-Input NAND | DIP-14_W7.62mm | SN74ACT00N | 595-SN74ACT00N
7 | Logic | 1 | U6 | 74AHCT04 | Texas Instruments Hex Inverter | DIP-14_W7.62mm | SN74AHCT04N | 595-SN74AHCT04N
8 | Logic | 1 | U7 | 74LS08 | Texas Instruments 4-Gate AND | DIP-14_W7.62mm | SN74LS08N | 595-SN74LS08N
9 | Logic | 1 | U8 | 4075 | Texas Instruments Triple 3-input OR Gate | DIP-14_W7.62mm | CD4075BE | 595-CD4075BE

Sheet: Off-Board Items
Item # | Description | Type | Qty | MFR Part # | Mouser Part # | Notes
18 | Jumpers | Jumper | 6 | JM-2BK-61 | 306-JM-2BK-61 | Shunts for the jumper headers
30 | Fiber RX/TX Eval boards. | Connector | 1 | AFBR-0548Z | 630-AFBR-0548Z | Plugs into base J7 and J10. Modified: bent interface pins removed and replaced with straight pins facing vertically down (long side opposite the fiber ports). Replacement pins: generic 3-position 2.54 mm pitch header (no part number), cut from a longer strip on hand
31 | Base Board PCB empty board | PCB | 1 | NA | NA
41 | Logic Board PCB empty board | PCB | 1 | NA | NA
42 | Mounting Base Base Housing(Phoenix Contact) | Housing | 1 | 2278500 | 651-2278500
43 | Upper Housing Part(Phoeix Contact) | Housing | 1 | 2278526 | 651-2278526
44 | Housing Cover(Phoeix Contact) | Housing | 1 | 2278542 | 651-2278542
45 | Housing Filler Plug(Phoeix Contact) | Housing | 2 | 2896238 | 651-2896238

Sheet: Final Testing
Tested IO or Device | Test Description | Assembly 1 | Assembly 2
50-ohm termination jumpers | 50 ohms across BNC connectors when jumper present. BNC open if jumper removed. | Pass | Pass
Local-Remote switch | Local and Remote status outputs toggle properly with switch input. | Pass | Pass
Normal-OS switch | Normal and OS feedbacks are triggered appropiately. | Pass | Pass
Power status feedback | HIGH(24V) when PWR and EXT PWR are present | Pass | Pass
Inhibbit Summation Status (inh2 jumper) | Triggered on inh2 jumper | Pass | Pass
Inhibbit Summation Status (inh3 jumper) | Triggered on inh3 jumper | Pass | Pass
Inhibit 1 feedback | triggers HIGH if inhibit 1 input LO and viceversa | Pass | Pass
input selection jumper | Propely labeled and selects the appropiate input | Pass | Pass
output selection jumper | Propely labeled and selects the appropiate output | Pass | Pass
Inhibit 2 jumper | Stops Pulses and relfects properly on INH summation | Pass | Pass
Inhibit 3 jumper | Stops Pulses and relfects properly on INH summation | Pass | Pass
Trigger_sts_fb | tested on BNC triggering | Pass | Pass
OS button | allows one pulse when proper switch setup and button pressede | Pass | Pass
inhibit 2 in/out | inhibit 2 input signal propelry closes the selected voltage on INH2 feedback. | Pass | Pass
inhibit 3 in/out | inhibit 3 input signal propelry closes the selected voltage on INH3 feedback. | Pass | Pass
Remote OS signal input | When swtiches are appropiate, remote OS is selected and Remote OS Signal is received a single pulse is observed at the output | Pass | Pass
BNC input | Input works properly | Pass | Pass
BNC output | Output works properly | Pass | Pass
Fiber input | Input works properly | Pass | Pass
fiber output | Output works properly | Pass | Pass
INH1 stops pulses | When pulsing, INH1 LOW stops the pulses. | Pass | Pass
INH2 stops pulses | When Pulsing INH2 LOW stops the pulses. | Pass | Pass
INH3 stops pulses | When Pulsing INH3 LOW stops the pulses. | Pass | Pass

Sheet: Notes
Source: KiCad schematics baseboard.kicad_sch and logicboard.kicad_sch in Trigger_Board_Working (generated 2026-10-06).
Refs prefixed B: = Base board, L: = Logic board.
MFR/Mouser part numbers come from Documentation/Final_Trigger_Board_BOM.xlsx (FINAL BOM sheet), matched by reference designator. Rows marked DISCREPANCY or CHECK disagree with the schematic or with the part number.
Not included: bare PCBs, jumper shunts for JP1-JP6, IC sockets, standoffs, screws, cables. None are in the schematic - add if used in production.
Footprint REF** (boards:base_board_NH) on the base board is a non-electrical board footprint, not a part.

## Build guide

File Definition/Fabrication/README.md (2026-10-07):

# Fabrication

Everything needed to reorder the bare boards.

- Base_Board/ and Logic_Board/: Gerber zip, ORDER_SPEC.md (options to select at the fab), and the original JLCPCB order package (proof of what was built; its internal "ok" folder is the fab's own CAM output and is not needed for reordering).
- CHECKSUMS.sha256: SHA-256 of every file here. Verify with `sha256sum -c CHECKSUMS.sha256` (Linux/Mac) or Get-FileHash (Windows).
- Verified 2026-10-07: the Gerbers inside both JLCPCB packages match these Gerber zips (base byte-identical; logic identical except creation timestamps), and copper, zones, drills, outline and mask openings match the KiCad project files. Silkscreen, paste layers and pad shapes were not checked.
- Parts and assembly are separate: see Documentation for the BOM. The fiber evaluation boards are not in the Gerbers and must be sourced separately.

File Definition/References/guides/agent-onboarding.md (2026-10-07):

---
title: Agent Onboarding (TEMPLATE -- Phase-1 baseline; Phase-2 agent fills this in)
audience: agent
agent_consumable: true
binding: false
governed_by: T7.C1.S17
note: Phase-1 mechanical baseline emitted by new-project.ps1 per T7.C1.S17.SS5. The Phase-2 agent-bootstrap fills the bracketed sections with module-specific content. Guidance, not bylaws -- cite rules by id; never restate (T7.C1.S17.SS4).
updated: 2026-06-04
---

# <MODULE> Agent Onboarding

**This is a lens, not the source of truth.** It points at binding rules by id; the cited Section governs (T7.C1.S17.SS4). Where this guide and a Section disagree, the Section wins -- log the discrepancy in `agent-discovery-log.md`.

## 1. Who you are / what this repo is
<Phase 2: module identity, project type, what this repo governs/contains, and what it pins (FW, CS).>

## 2. Canonical paths
- Bylaws / content: <Phase 2: this module's canonical homes>.
- Scripts: `Workflows/` (thin delegates to the pinned Framework's `Definition/References/scripts/`).
- History: `change-log.md` + `minutes/`. Cross-agent transport: a non-codified dev-period handoff channel -- never named by literal path in bylaws (fw-T8.C1.S4.SS7).

## 3. Inherited Framework disciplines (rule-id -> one-line effect)
- fw-T7.C1.S13.SS2 -- commit pipeline validate -> push -> tag.
- fw-T7.C1.S13.SS3 / fw-T7.C1.S14.SS2 -- read the script transcript; "done" != "clean".
- fw-T7.C1.S9.SS8 -- double-check changes; verify completeness claims against committed git state, not the working-tree mount.
- fw-T7.C1.S14.SS7 -- end every response with a `Next Steps:` block.
- fw-T7.C1.S17 -- keep this onboarding home living; record discoveries; graduate stable lessons.
- fw-T11.C1.S8 -- framework tags first in a paired ship.
<Phase 2: add module-specific rules + the cs-/fw- quickref pointers.>

## 4. First-action checklist
1. Read AGENTS.md + this guide + the discovery log.
2. Confirm state off committed git, not a possibly-fogged working-tree read.
3. Change -> operator runs validate/push (read transcript) -> tag.
4. End every response with `Next Steps:`.

## Related
fw-T7.C1.S17 (this rule), fw-T7.C1.S1, fw-T7.C1.S9, fw-T7.C1.S13, fw-T7.C1.S14 -- read the Sections for normative detail.

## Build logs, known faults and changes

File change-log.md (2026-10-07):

# Change Log

Append-only per-commit ledger (fw-T8.C1.S1). Newest entries at the top.

## 2026-10-07 -- fix: correct owner EntraID to fsaenz

- **by:** fsaenz
- **commit:** *(pending)*
- **branch:** master
- **scope:** project
- **rules cited:** fw-T2.C1.S10.SS1, fw-T8.C1.S1.SS1

Corrected the owner's EntraID from the inferred `fjsaenz` to `fsaenz` in
`Workflows/ownership/parties.yaml`, `README.md`, `docs/README.md` and
`Project/STANDING-STATE.md`. The two earlier entries below carry `by: fjsaenz`; the ledger is
append-only, so they are left as written and this entry supersedes them.

## 2026-10-07 -- fix: set owner email to work address

- **by:** fjsaenz
- **commit:** *(pending)*
- **branch:** master
- **scope:** project
- **rules cited:** fw-T2.C1.S10.SS1, fw-T8.C1.S1.SS1

Changed the owner party's email in `Workflows/ownership/parties.yaml` from the personal address to
the work address (`fsaenz@reveam.com`). No other content change.

## 2026-10-07 -- dev-acs-egun-trig-pcbdesign-v0.1.0 MINOR none: Phase-2 bootstrap + released Trigger Board design content

- **by:** fjsaenz
- **commit:** *(pending first commit)*
- **branch:** main
- **scope:** project
- **rules cited:** cs-T5.C1.S3, cs-T5.C1.S17, fw-T4.C1.S2, fw-T4.C1.S6.SS5, fw-T11.C1.S1, fw-T9.C1.S5, fw-T8.C1.S9, fw-T2.C1.S10, fw-T6.C1.S4

Completed the Phase-2 bootstrap. Classified the project: category **ACS** -> **EGUN** -> **TRIG**,
project-type token **PCBDesign**, giving `DEV-ACS-EGUN-TRIG_PCBDesign` (operator-elected name;
`TRIG` is an operator-chosen segment under `EGUN`; the CS name gate reports CANONICAL, with an advisory
that `PCBDesign` is outside the catalogued project-type set, accepted structurally as in the sibling
DDS repo); function `TimingSignal` (cs-T2), type-class `PCB`,
discipline **D040 Electrical**; flat layout (no eigen-module, no `composition.yaml`).

Populated `compatibility.yaml` (scope), `interfaces.yaml` (nine active interfaces), the four-file
`docs/` suite, `README.md`, and the ownership registries (owner `pty-francisco-saenz`). Placed the
released design content from the Trigger Board package: KiCad projects in `Definition/Drawings/`
(PDF plots and renders in `Drawings/exports/`), the reorder kit and unzipped Gerbers in
`Definition/Fabrication/`, BOMs in `Definition/Equipment/`, block diagram in
`Definition/Architecture/`, Falstad simulation in `Definition/Calculations/`, and the system
documentation and design notes in `Definition/Narratives/` (renamed lowercase-hyphen). Source
files were not renamed. Extended `access.yaml` (swap-only for binary content) and `.gitattributes`
(binary rules for Gerbers, drills and exports so checksums hold). Known: two `ORDER_SPEC.md`
files fail `Definition/Fabrication/CHECKSUMS.sha256` (edited after the checksums were made).

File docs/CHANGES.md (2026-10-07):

# DEV-ACS-EGUN-TRIG_PCBDesign -- Changes

This is the curated, human-readable change narrative. The append-only per-commit ledger is
[`change-log.md`](../change-log.md) (fw-T8.C1.S1); this file (fw-T8.C1.S9.SS2) summarizes the
changes that matter for a reader catching up on the design.

## Recent

**Released Trigger Board design landed (v0.1.0).** The released Base board ("pin version",
6-layer) and Logic board (rev 0.2, 4-layer) KiCad projects, their released Gerbers and JLCPCB
reorder kit (orders 9354260A_Y6 and _Y8), the corrected master BOM, the Falstad simulation, the
block diagram, and the system documentation were placed under `Definition/` (Drawings,
Fabrication, Equipment, Calculations, Architecture, Narratives). Source files keep their
tool-given names per fw-T4.C1.S6.SS5. See [`change-log.md`](../change-log.md) for the commit.

**Phase 2 bootstrap (v0.1.0).** The repository was scaffolded in Phase 1 and completed through
Phase 2 per `BOOTSTRAP.md`: classified as ACS -> EGUN -> TRIG (function `TimingSignal`; discipline
D040 Electrical), scope and ownership populated, interface manifest authored, doc-set created.

## Notable historical

Nothing yet -- v0.1.0 records the released boards as the baseline. Planned future work (not
started): an all-SMD redesign for fab assembly, removing the fiber evaluation boards in favor of
on-board optics, and possibly merging the two boards. It will branch from this baseline and be
narrated here when it begins.

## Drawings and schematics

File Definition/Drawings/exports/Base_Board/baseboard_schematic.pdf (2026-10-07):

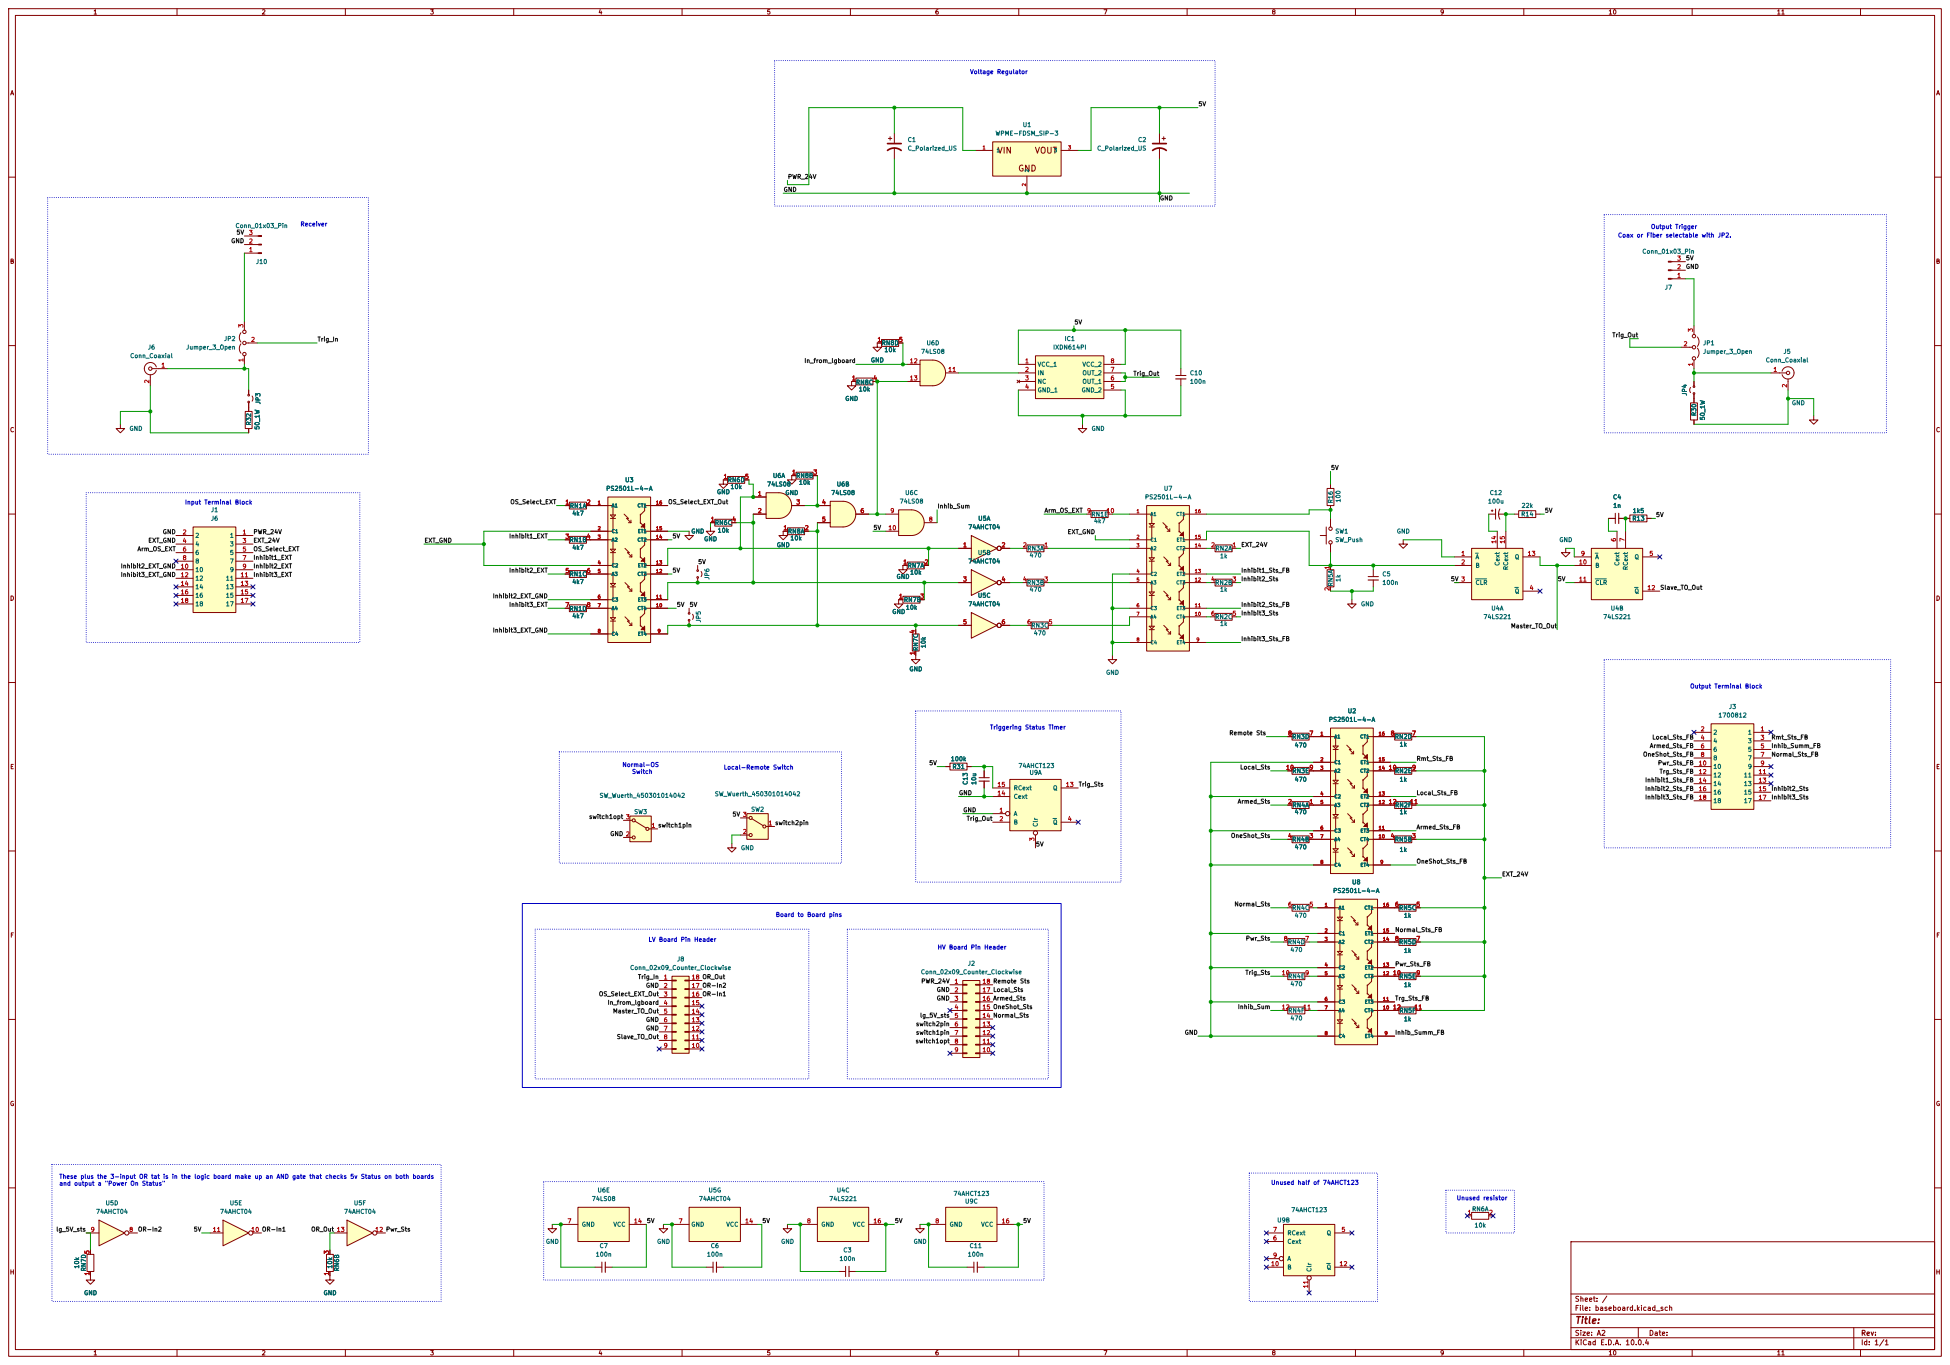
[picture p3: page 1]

Coax or Fiber selectable with JP2. Output Trigger
J7 Conn_01x03_Pin1

5V GND
Local-Remote Switch Normal-OS
Switch

Board to Board pins

These plus the 3-input OR tat is in the logic board make up an AND gate that checks 5v Status on both boards and output a "Power On Status"

Size: A2 | Rev:
KiCad E.D.A. 10.0.4 | Id: 1/1

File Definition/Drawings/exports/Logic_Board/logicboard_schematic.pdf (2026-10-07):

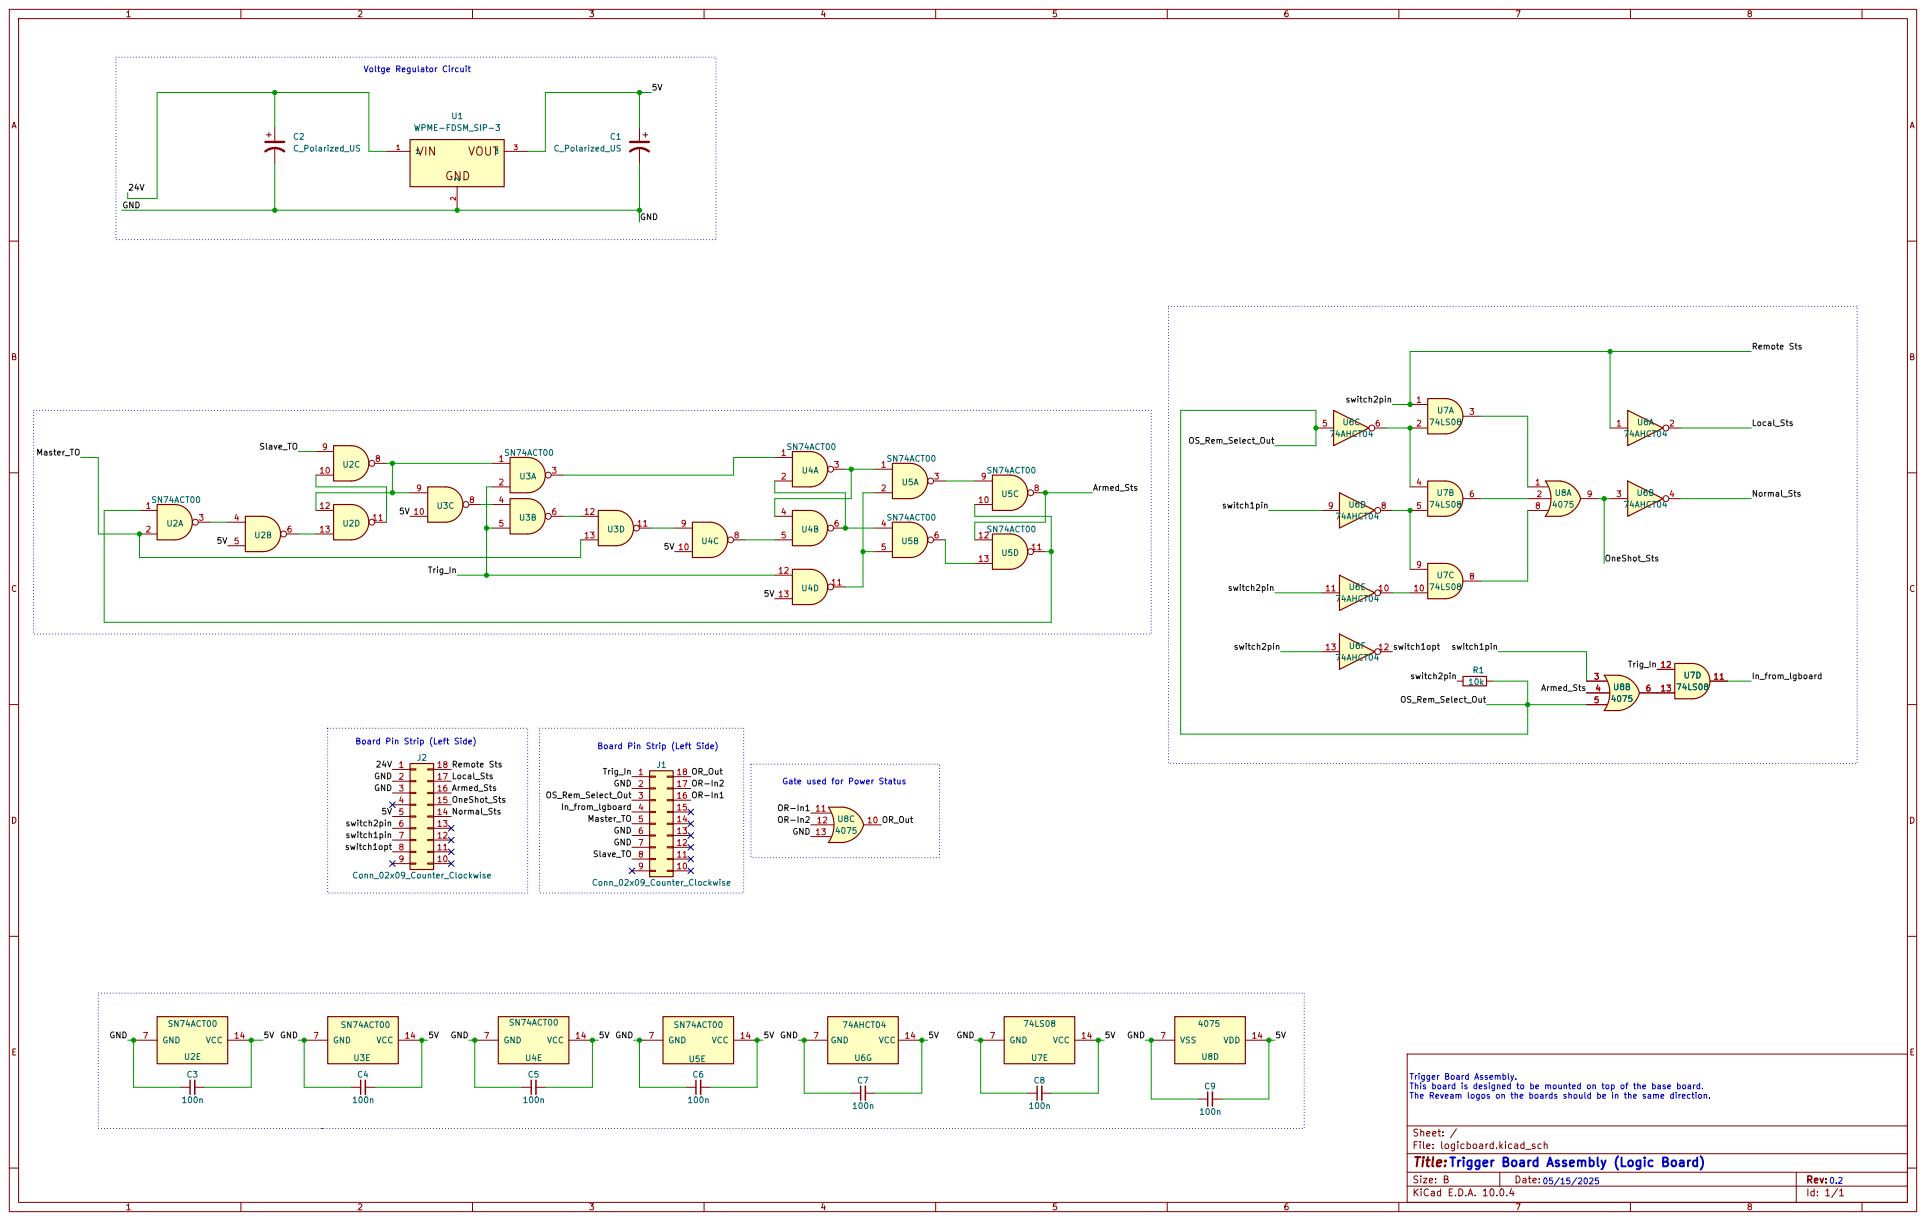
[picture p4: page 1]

Trigger Board Assembly. This board is designed to be mounted on top of the base board. The Reveam logos on the boards should be in the same direction.

Size: B | 05/15/2025 | Rev: 0.2
KiCad E.D.A. 10.0.4 | | Id: 1/1

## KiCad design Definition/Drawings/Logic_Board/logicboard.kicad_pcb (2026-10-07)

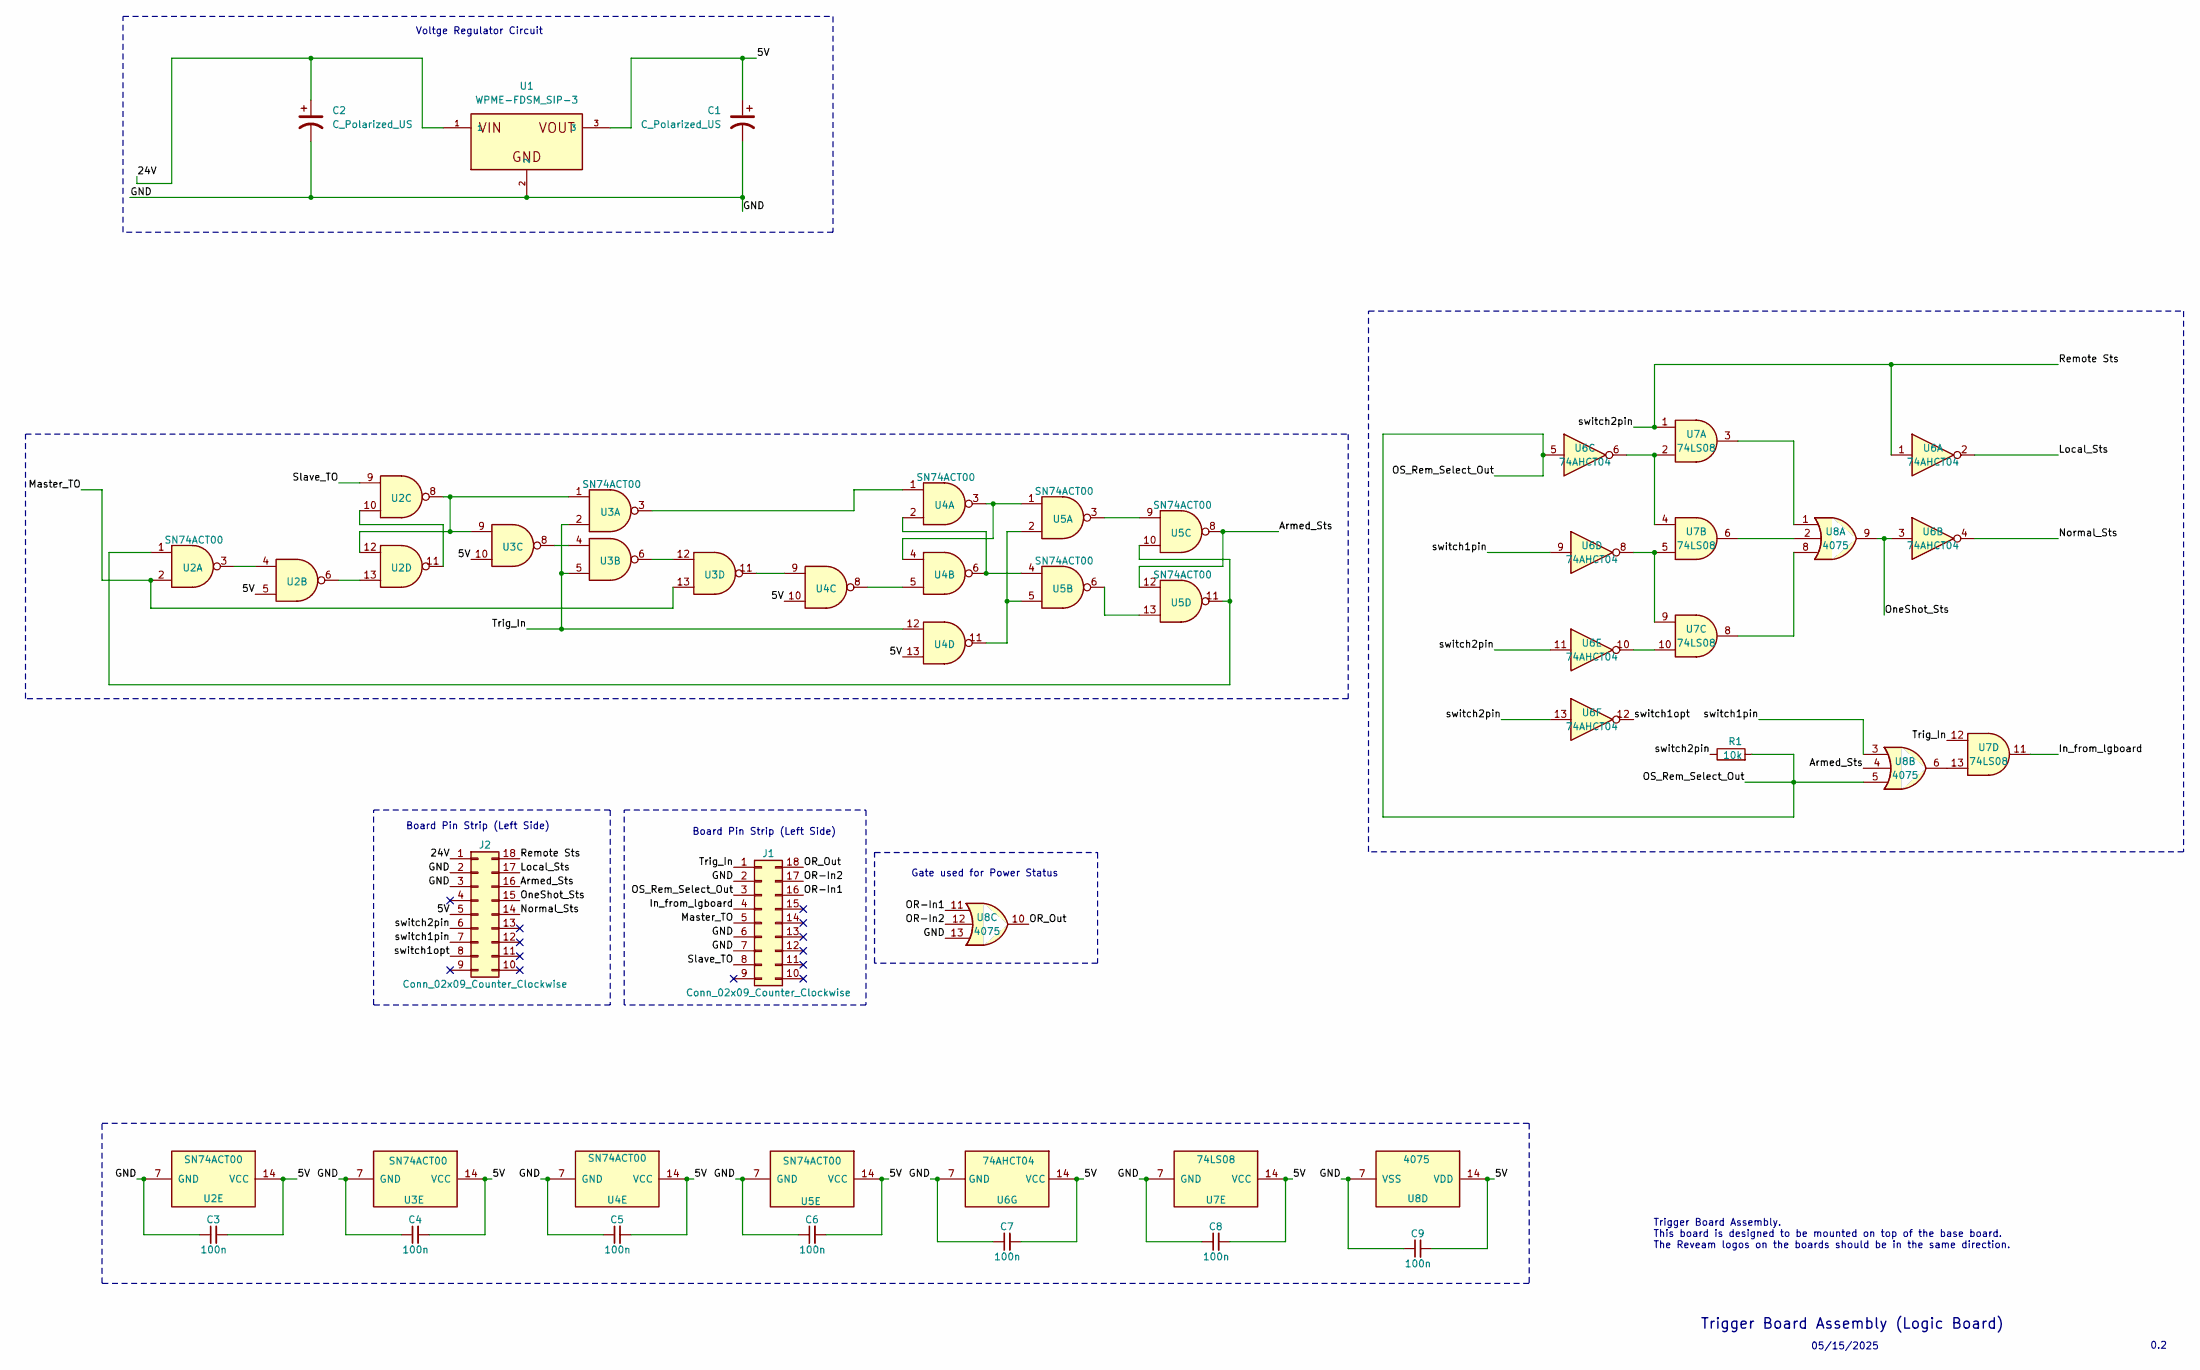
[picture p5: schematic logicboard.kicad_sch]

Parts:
C1, C2: C_Polarized_US; CP_Radial_D8.0mm_P3.80mm
C3, C4, C5, C6, C7, C8, C9: 100n; C_Disc_D5.0mm_W2.5mm_P2.50mm
J1, J2: Conn_02x09_Counter_Clockwise; PinHeader_2x09_P2.54mm_Vertical
R1: 10k; R_Axial_DIN0207_L6.3mm_D2.5mm_P10.16mm_Horizontal
U1: WPME-FDSM_SIP-3; CONV_173010578
U2, U3, U4, U5: SN74ACT00; DIP-14_W7.62mm
U6: 74AHCT04; DIP-14_W7.62mm
U7: 74LS08; DIP-14_W7.62mm
U8: 4075; DIP-14_W7.62mm

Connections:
/5V: C1.1, C3.2, C4.2, C5.2, C6.2, C7.2, C8.2, C9.2, J2.5, U1.3, U2.5, U2.14 (VCC), U3.10, U3.14 (VCC), U4.10, U4.13, U4.14 (VCC), U5.14 (VCC), U6.14 (VCC), U7.14 (VCC), U8.14 (VDD)
/24V: C2.1, J2.1, U1.1
/Armed_Sts: J2.16, U5.8, U5.12, U8.4
/GND: C1.2, C2.2, C3.1, C4.1, C5.1, C6.1, C7.1, C8.1, C9.1, J1.2, J1.6, J1.7, J2.2, J2.3, U1.2, U2.7 (GND), U3.7 (GND), U4.7 (GND), U5.7 (GND), U6.7 (GND), U7.7 (GND), U8.7 (VSS), U8.13
/In_from_lgboard: J1.4, U7.11
/Local_Sts: J2.17, U6.2
/Master_TO: J1.5, U2.2, U3.13
/Normal_Sts: J2.14, U6.4
/OR-In1: J1.16, U8.11
/OR-In2: J1.17, U8.12
/OR_Out: J1.18, U8.10
/OS_Rem_Select_Out: J1.3, R1.2, U6.5, U8.5
/OneShot_Sts: J2.15, U6.3, U8.9
/Remote Sts: J2.6, J2.18, R1.1, U6.1, U6.11, U6.13, U7.1
/Slave_TO: J1.8, U2.9
/Trig_In: J1.1, U3.2, U3.5, U4.12, U7.12
/switch1opt: J2.8, U6.12
/switch1pin: J2.7, U6.9, U8.3
unnamed: U2.1, U5.10, U5.11
unnamed: U2.3, U2.4
unnamed: U2.10, U2.11
unnamed: U2.8, U2.12, U3.1, U3.9
unnamed: U2.6, U2.13
unnamed: U3.3, U4.1
unnamed: U3.4, U3.8
unnamed: U3.11, U4.9
unnamed: U3.6, U3.12
unnamed: U4.2, U4.6, U5.4
unnamed: U4.3, U4.4, U5.1
unnamed: U4.5, U4.8
unnamed: U4.11, U5.2, U5.5
unnamed: U5.3, U5.9
unnamed: U5.6, U5.13
unnamed: U6.6, U7.2, U7.4
unnamed: U6.8, U7.5, U7.9
unnamed: U6.10, U7.10
unnamed: U7.3, U8.1
unnamed: U7.6, U8.2
unnamed: U7.8, U8.8
unnamed: U7.13, U8.6

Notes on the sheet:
Voltge Regulator Circuit
Board Pin Strip (Left Side)
05/15/2025
Gate used for Power Status
0.2
Trigger Board Assembly. This board is designed to be mounted on top of the base board. The Reveam logos on the boards should be in the same direction.
Trigger Board Assembly (Logic Board)

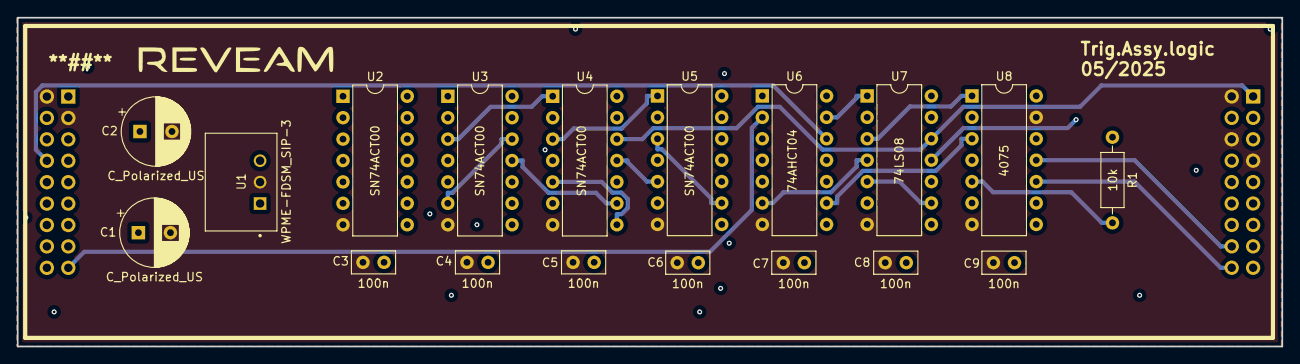
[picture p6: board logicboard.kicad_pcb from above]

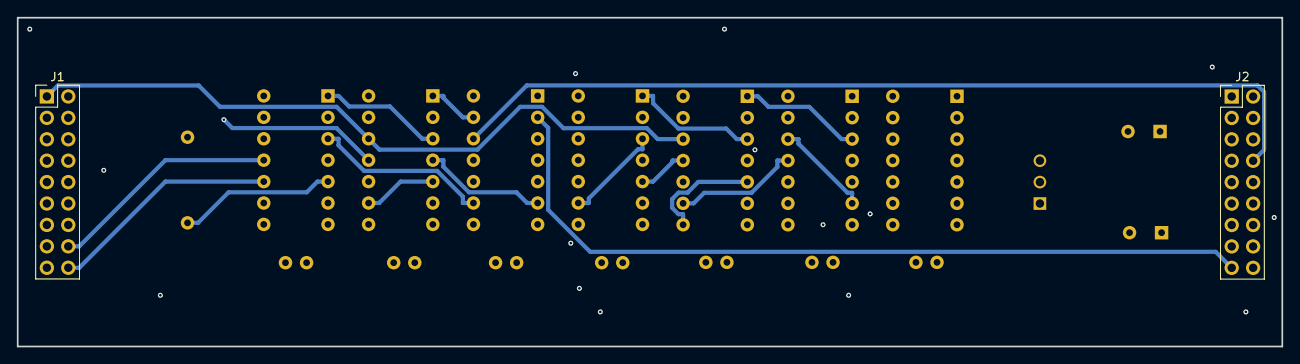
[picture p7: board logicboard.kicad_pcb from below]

Board: 4 copper layers, 150.0 x 39.0 mm, 21 parts (2 on the bottom side), 40 nets.

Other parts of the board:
*: LOGO

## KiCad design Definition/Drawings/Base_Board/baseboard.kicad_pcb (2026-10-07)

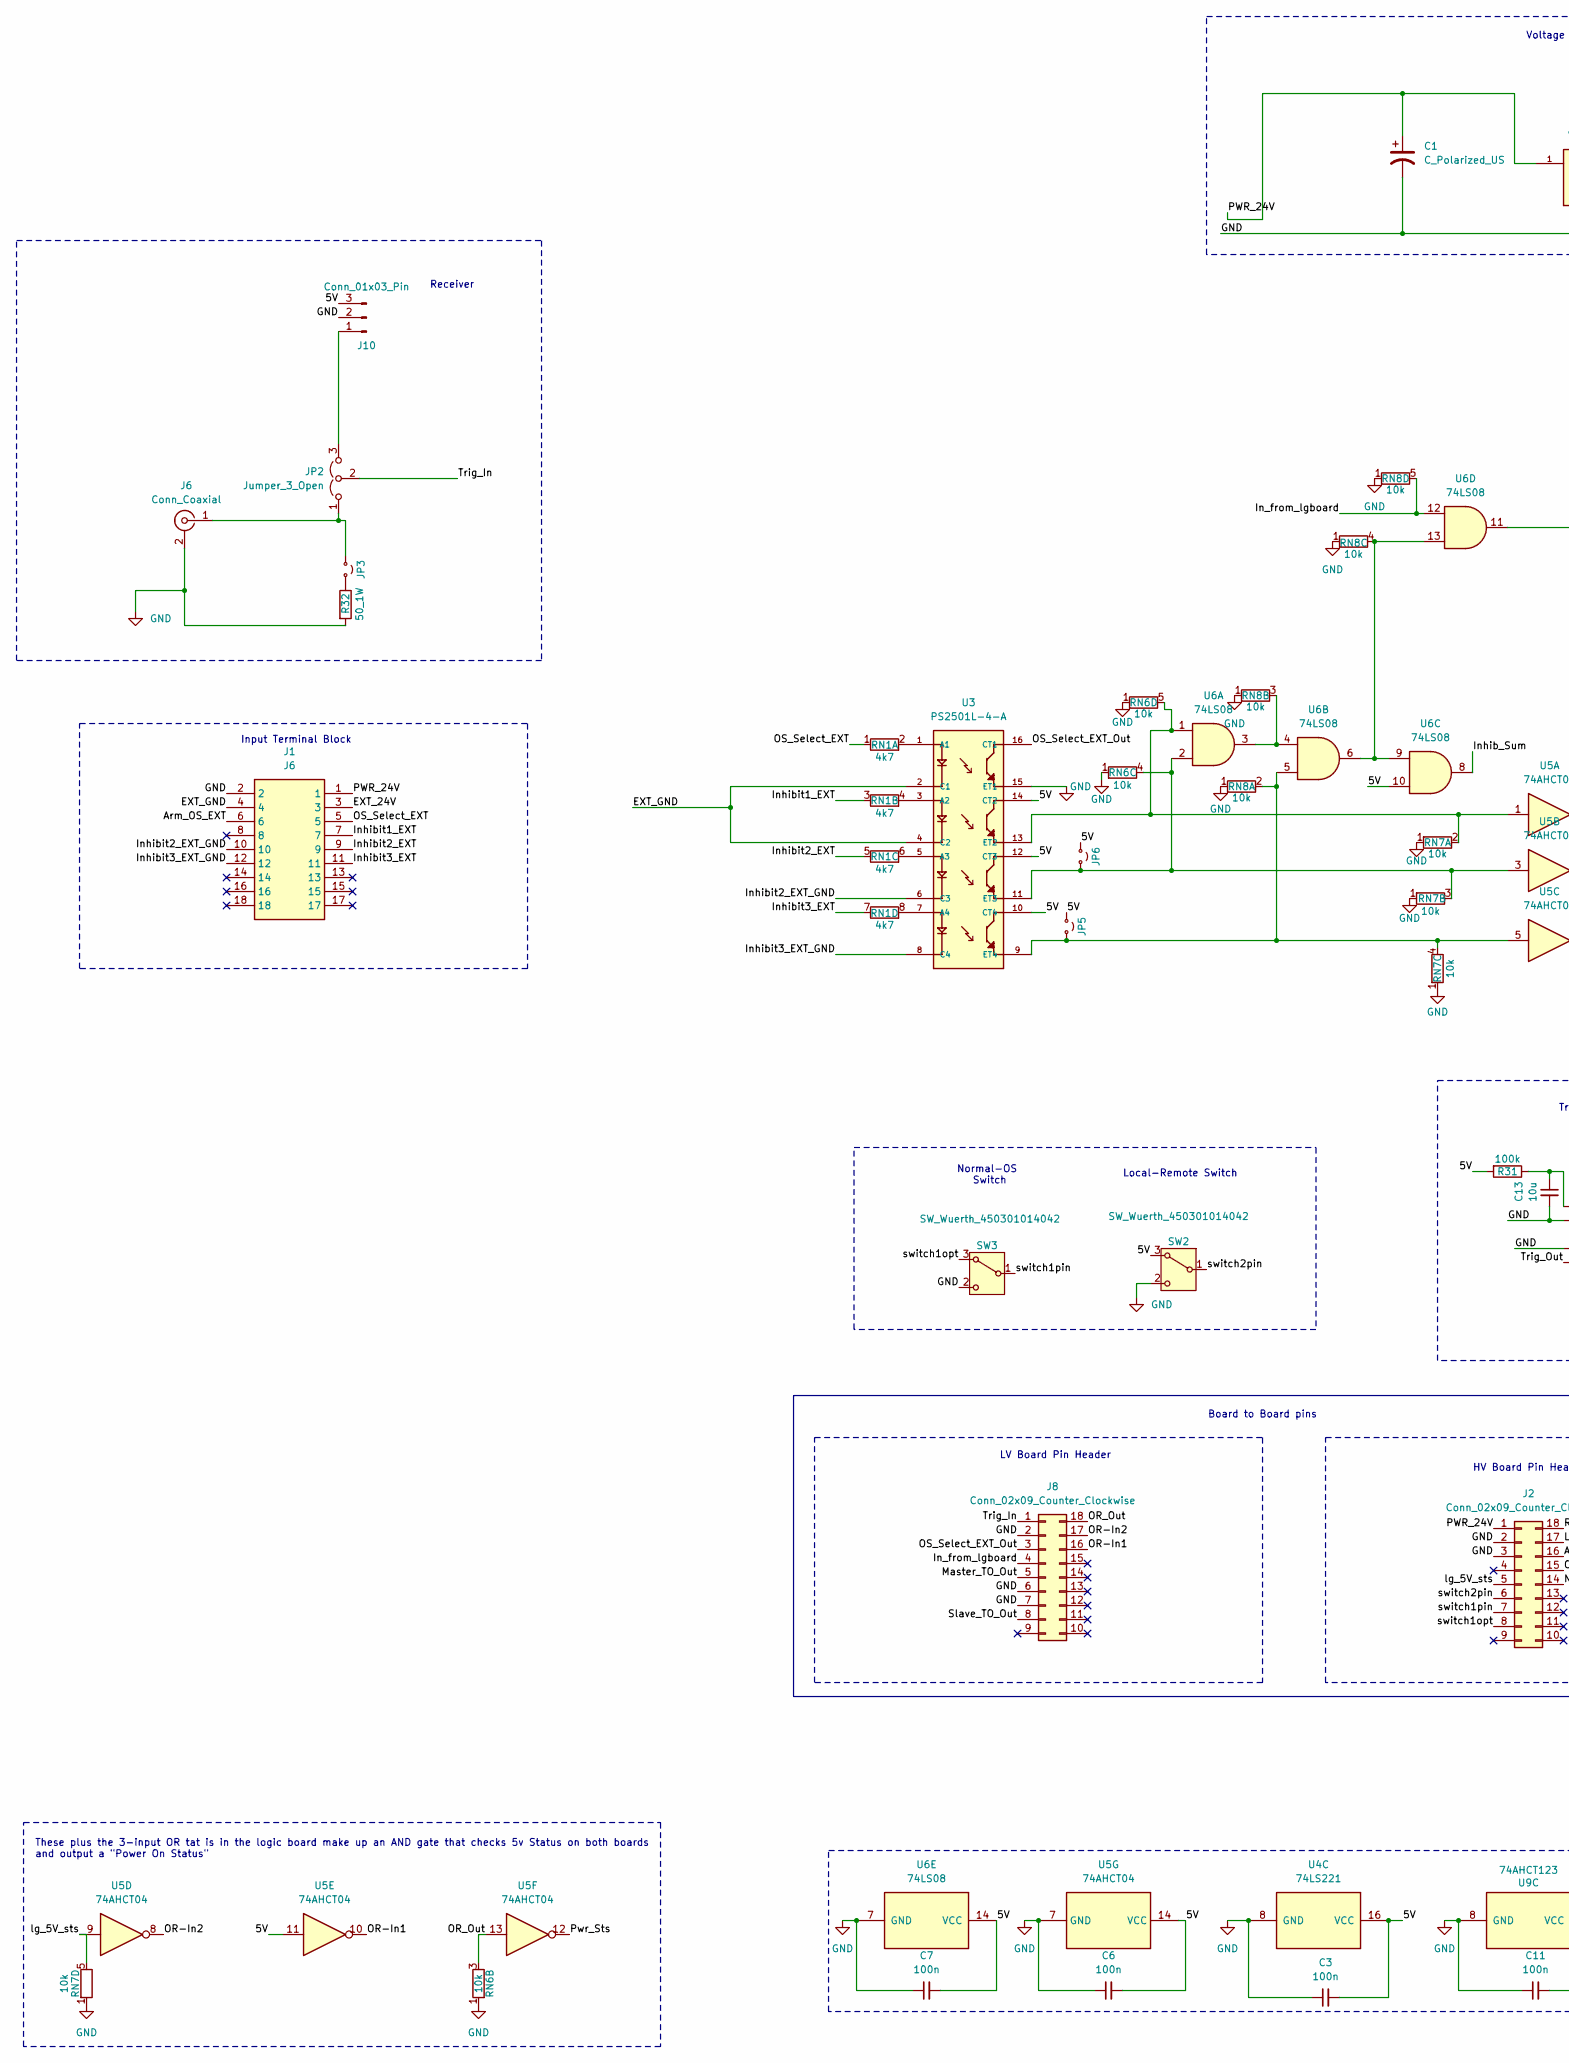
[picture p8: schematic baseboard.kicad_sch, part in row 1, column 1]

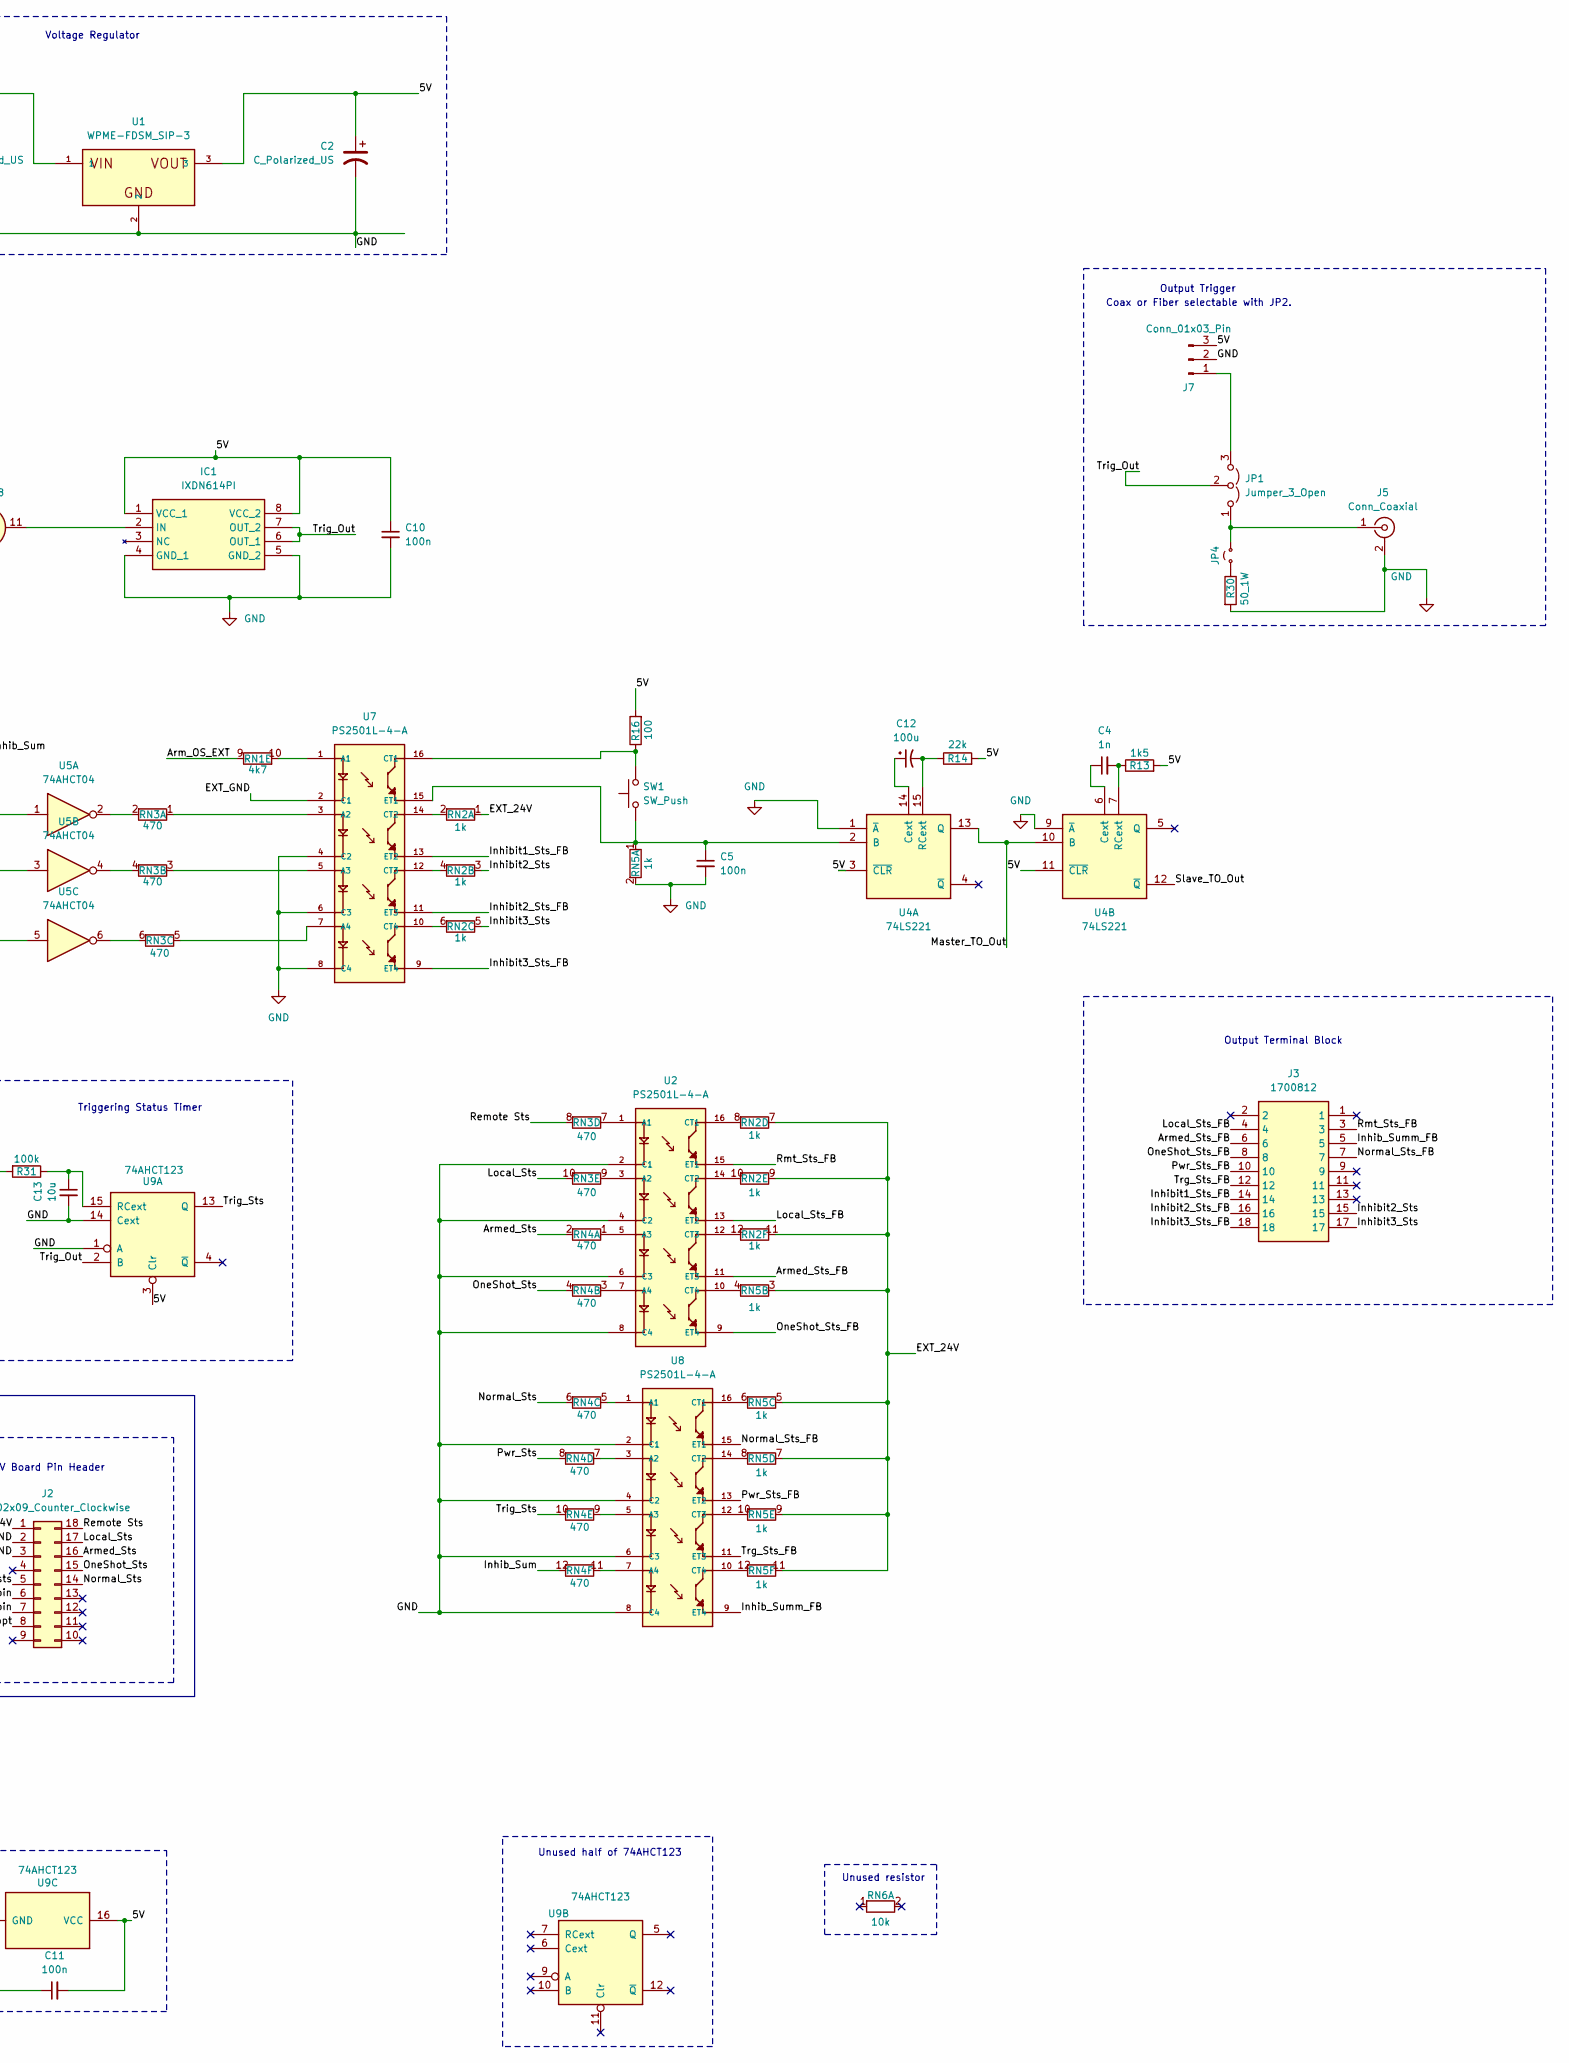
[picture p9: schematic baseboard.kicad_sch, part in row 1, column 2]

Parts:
C1, C2: C_Polarized_US; CP_Radial_D6.3mm_P2.50mm
C3, C5, C6, C7, C10, C11: 100n; C_Disc_D4.7mm_W2.5mm_P5.00mm
C4: 1n; C_Disc_D4.7mm_W2.5mm_P5.00mm
C12: 100u; CP_Radial_D4.0mm_P1.50mm
C13: 10u; C_Disc_D4.7mm_W2.5mm_P5.00mm
IC1: IXDN614PI; DIP-8_W7.62mm; Manufacturer_Part_Number IXDN614PI
J1: J6; 1700812; Manufacturer_Part_Number 1700812
J2, J8: Conn_02x09_Counter_Clockwise; PinSocket_2x09_P2.54mm_Vertical
J3: 1700812; Manufacturer_Part_Number 1700812
J5, J6: Conn_Coaxial; BNC_TEConnectivity_1478204_Vertical
J7, J10: Conn_01x03_Pin; FanPinHeader_1x03_P2.54mm_Vertical
JP1, JP2: Jumper_3_Open; PinHeader_1x03_P2.54mm_Vertical
JP3, JP4, JP5, JP6: Jumper_2_Small_Open; TestPoint_2Pads_Pitch2.54mm_Drill0.8mm
R13: 1k5; R_Axial_DIN0207_L6.3mm_D2.5mm_P10.16mm_Horizontal
R14: 22k; R_Axial_DIN0207_L6.3mm_D2.5mm_P10.16mm_Horizontal
R16: 100; R_Axial_DIN0207_L6.3mm_D2.5mm_P10.16mm_Horizontal
R30, R32: 50_1W; R_Axial_DIN0411_L9.9mm_D3.6mm_P15.24mm_Horizontal
R31: 100k; R_Axial_DIN0207_L6.3mm_D2.5mm_P10.16mm_Horizontal
RN1: 4k7; R_Array_SIP10
RN2, RN5: 1k; R_Array_SIP12
RN3: 470; R_Array_SIP10
RN4: 470; R_Array_SIP12
RN6, RN7, RN8: 10k; R_Array_SIP5
SW1: SW_Push; SW_PUSH_6mm_H5mm
SW2, SW3: SW_Wuerth_450301014042; SW_Slide-03_Wuerth-WS-SLTV_10x2.5x6.4_P2.54mm
U1: WPME-FDSM_SIP-3; CONV_173010578
U2, U3, U7, U8: PS2501L-4-A; DIP-16_W7.62mm
U4: 74LS221; DIP-16_W7.62mm
U5: 74AHCT04; DIP-14_W7.62mm
U6: 74LS08; DIP-14_W7.62mm
U9: 74AHCT123; DIP-16_W7.62mm

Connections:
/5V: C2.1, C3.2, C6.2, C7.2, C10.1, C11.2, IC1.1 (VCC_1), IC1.8 (VCC_2), J7.3, J10.3, JP5.1 (A), JP6.1 (A), R13.2, R14.2, R16.2, R31.2, SW2.3 (A), U1.3, U3.10 (CT4), U3.12 (CT3), U3.14 (CT2), U4.3 (~CLR), U4.11 (~CLR), U4.16 (VCC), U5.11, U5.14 (VCC), U6.10, U6.14 (VCC), U9.3 (Clr), U9.16 (VCC)
/Arm_OS_EXT: J1.6, RN1.9 (R5.1)
/Armed_Sts: J2.16, RN4.2 (R1.2)
/Armed_Sts_FB: J3.6, U2.11 (ET3)
/EXT_24V: J1.3, RN2.1 (R1.1), RN2.7 (R4.1), RN2.9 (R5.1), RN2.11 (R6.1), RN5.3 (R2.1), RN5.5 (R3.1), RN5.7 (R4.1), RN5.9 (R5.1), RN5.11 (R6.1)
/EXT_GND: J1.4, U3.2 (C1), U3.4 (C2), U7.2 (C1)
/In_from_lgboard: J8.4, RN8.5 (R4.2), U6.12
/Inhib_Sum: RN4.12 (R6.2), U6.8
/Inhib_Summ_FB: J3.5, U8.9 (ET4)
/Inhibit1_EXT: J1.7, RN1.3 (R2.1)
/Inhibit1_Sts_FB: J3.14, U7.13 (ET2)
/Inhibit2_EXT: J1.9, RN1.5 (R3.1)
/Inhibit2_EXT_GND: J1.10, U3.6 (C3)
/Inhibit2_Sts: J3.15, RN2.3 (R2.1)
/Inhibit2_Sts_FB: J3.16, U7.11 (ET3)
/Inhibit3_EXT: J1.11, RN1.7 (R4.1)
/Inhibit3_EXT_GND: J1.12, U3.8 (C4)
/Inhibit3_Sts: J3.17, RN2.5 (R3.1)
/Inhibit3_Sts_FB: J3.18, U7.9 (ET4)
/Local_Sts: J2.17, RN3.10 (R5.2)
/Local_Sts_FB: J3.4, U2.13 (ET2)
/Master_TO_Out: J8.5, U4.10 (B), U4.13 (Q)
/Normal_Sts: J2.14, RN4.6 (R3.2)
/Normal_Sts_FB: J3.7, U8.15 (ET1)
/OR-In1: J8.16, U5.10
/OR-In2: J8.17, U5.8
/OR_Out: J8.18, RN6.3 (R2.2), U5.13
/OS_Select_EXT: J1.5, RN1.1 (R1.1)
/OS_Select_EXT_Out: J8.3, U3.16 (CT1)
/OneShot_Sts: J2.15, RN4.4 (R2.2)
/OneShot_Sts_FB: J3.8, U2.9 (ET4)
/PWR_24V: C1.1, J1.1, J2.1, U1.1
/Pwr_Sts: RN4.8 (R4.2), U5.12
/Pwr_Sts_FB: J3.10, U8.13 (ET2)
/Remote Sts: J2.18, RN3.8 (R4.2)
/Rmt_Sts_FB: J3.3, U2.15 (ET1)
/Slave_TO_Out: J8.8, U4.12 (~Q)
/Trg_Sts_FB: J3.12, U8.11 (ET3)
/Trig_In: J8.1, JP2.2 (C)
/Trig_Out: IC1.6 (OUT_1), IC1.7 (OUT_2), JP1.2 (C), U9.2 (B)
/Trig_Sts: RN4.10 (R5.2), U9.13 (Q)
/lg_5V_sts: J2.5, RN7.5 (R4.2), U5.9
/switch1opt: J2.8, SW3.3 (A)
/switch1pin: J2.7, SW3.1 (B)
/switch2pin: J2.6, SW2.1 (B)
GND: C1.2, C2.2, C3.1, C5.2, C6.1, C7.1, C10.2, C11.1, C13.2, IC1.4 (GND_1), IC1.5 (GND_2), J1.2, J2.2, J2.3, J5.2 (Ext), J6.2 (Ext), J7.2, J8.2, J8.6, J8.7, J10.2, R30.2, R32.2, RN5.2 (R1.2), RN6.1 (R1), RN7.1 (R1), RN8.1 (R1), SW2.2 (C), SW3.2 (C), U1.2, U2.2 (C1), U2.4 (C2), U2.6 (C3), U2.8 (C4), U3.15 (ET1), U4.1 (~A), U4.8 (GND), U4.9 (~A), U5.7 (GND), U6.7 (GND), U7.4 (C2), U7.6 (C3), U7.8 (C4), U8.2 (C1), U8.4 (C2), U8.6 (C3), U8.8 (C4), U9.1 (A), U9.8 (GND), U9.14 (Cext)
unnamed: IC1.2 (IN), U6.11
unnamed: J5.1 (In), JP1.1 (A), JP4.2 (B)
unnamed: J6.1 (In), JP2.1 (A), JP3.1 (A)
unnamed: J7.1, JP1.3 (B)
unnamed: J10.1, JP2.3 (B)
unnamed: JP3.2 (B), R32.1
unnamed: JP4.1 (A), R30.1
unnamed: JP5.2 (B), RN7.4 (R3.2), RN8.2 (R1.2), U3.9 (ET4), U5.5, U6.5
unnamed: JP6.2 (B), RN6.4 (R3.2), RN7.3 (R2.2), U3.11 (ET3), U5.3, U6.2
unnamed: RN1.2 (R1.2), U3.1 (A1)
unnamed: RN1.4 (R2.2), U3.3 (A2)
unnamed: RN1.6 (R3.2), U3.5 (A3)
unnamed: RN1.8 (R4.2), U3.7 (A4)
unnamed: RN1.10 (R5.2), U7.1 (A1)
unnamed: RN2.2 (R1.2), U7.14 (CT2)
unnamed: RN2.4 (R2.2), U7.12 (CT3)
unnamed: RN2.6 (R3.2), U7.10 (CT4)
unnamed: RN2.8 (R4.2), U2.16 (CT1)
unnamed: RN2.10 (R5.2), U2.14 (CT2)
unnamed: RN2.12 (R6.2), U2.12 (CT3)
unnamed: RN3.1 (R1.1), U7.3 (A2)
unnamed: RN3.2 (R1.2), U5.2
unnamed: RN3.3 (R2.1), U7.5 (A3)
unnamed: RN3.4 (R2.2), U5.4
unnamed: RN3.5 (R3.1), U7.7 (A4)
unnamed: RN3.6 (R3.2), U5.6
unnamed: RN3.7 (R4.1), U2.1 (A1)
unnamed: RN3.9 (R5.1), U2.3 (A2)
unnamed: RN4.1 (R1.1), U2.5 (A3)
unnamed: RN4.3 (R2.1), U2.7 (A4)
unnamed: RN4.5 (R3.1), U8.1 (A1)
unnamed: RN4.7 (R4.1), U8.3 (A2)
unnamed: RN4.9 (R5.1), U8.5 (A3)
unnamed: RN4.11 (R6.1), U8.7 (A4)
unnamed: C5.1, RN5.1 (R1.1), SW1.1, U4.2 (B), U7.15 (ET1)
unnamed: RN5.4 (R2.2), U2.10 (CT4)
unnamed: RN5.6 (R3.2), U8.16 (CT1)
unnamed: RN5.8 (R4.2), U8.14 (CT2)
unnamed: RN5.10 (R5.2), U8.12 (CT3)
unnamed: RN5.12 (R6.2), U8.10 (CT4)
unnamed: RN6.5 (R4.2), RN7.2 (R1.2), U3.13 (ET2), U5.1, U6.1
unnamed: RN8.3 (R2.2), U6.3, U6.4
unnamed: RN8.4 (R3.2), U6.6, U6.9, U6.13
unnamed: C12.1, U4.14 (Cext)
unnamed: C12.2, R14.1, U4.15 (RCext)
unnamed: C4.1, U4.6 (Cext)
unnamed: C4.2, R13.1, U4.7 (RCext)
unnamed: R16.1, SW1.2, U7.16 (CT1)
unnamed: C13.1, R31.1, U9.15 (RCext)

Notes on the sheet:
Triggering Status Timer
Voltage Regulator
Output Trigger
These plus the 3-input OR tat is in the logic board make up an AND gate that checks 5v Status on both boards and output a "Power On Status"
HV Board Pin Header
Receiver
Coax or Fiber selectable with JP2.
Local-Remote Switch
Normal-OS Switch
LV Board Pin Header
Board to Board pins
Unused resistor
Output Terminal Block
Unused half of 74AHCT123
Input Terminal Block

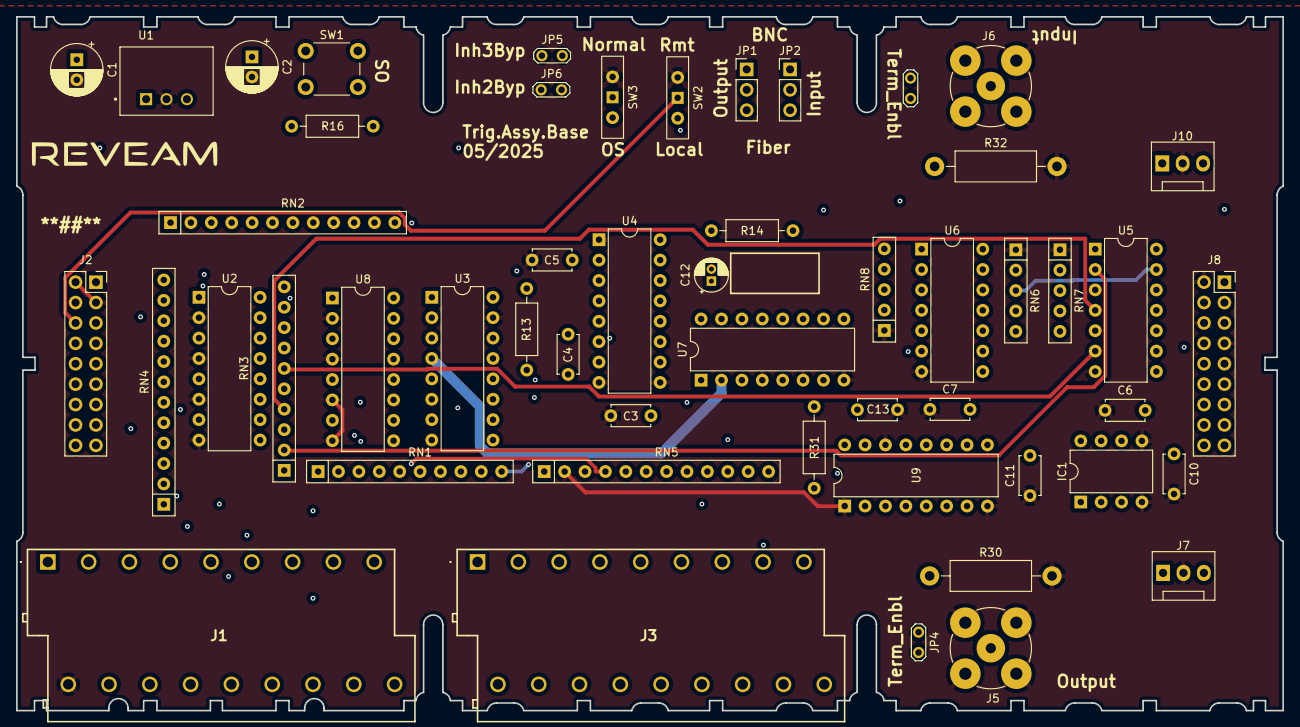
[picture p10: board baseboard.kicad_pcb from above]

Board: 6 copper layers, 157.7 x 86.4 mm, 53 parts (0 on the bottom side), 95 nets.

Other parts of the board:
*: LOGO
